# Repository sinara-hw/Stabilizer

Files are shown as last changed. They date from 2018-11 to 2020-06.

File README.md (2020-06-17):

# Stabilizer
2-channel microcontroller servo with EEM and Ethernet based on STM32 CPU

## Design Files

Design files (schematics, PCB layouts, BOMs) can be found at [Stabilizer/Releases](https://github.com/sinara-hw/Stabilizer/releases).

## Wiki

More information can be found on the [wiki](https://github.com/sinara-hw/Stabilizer/wiki).

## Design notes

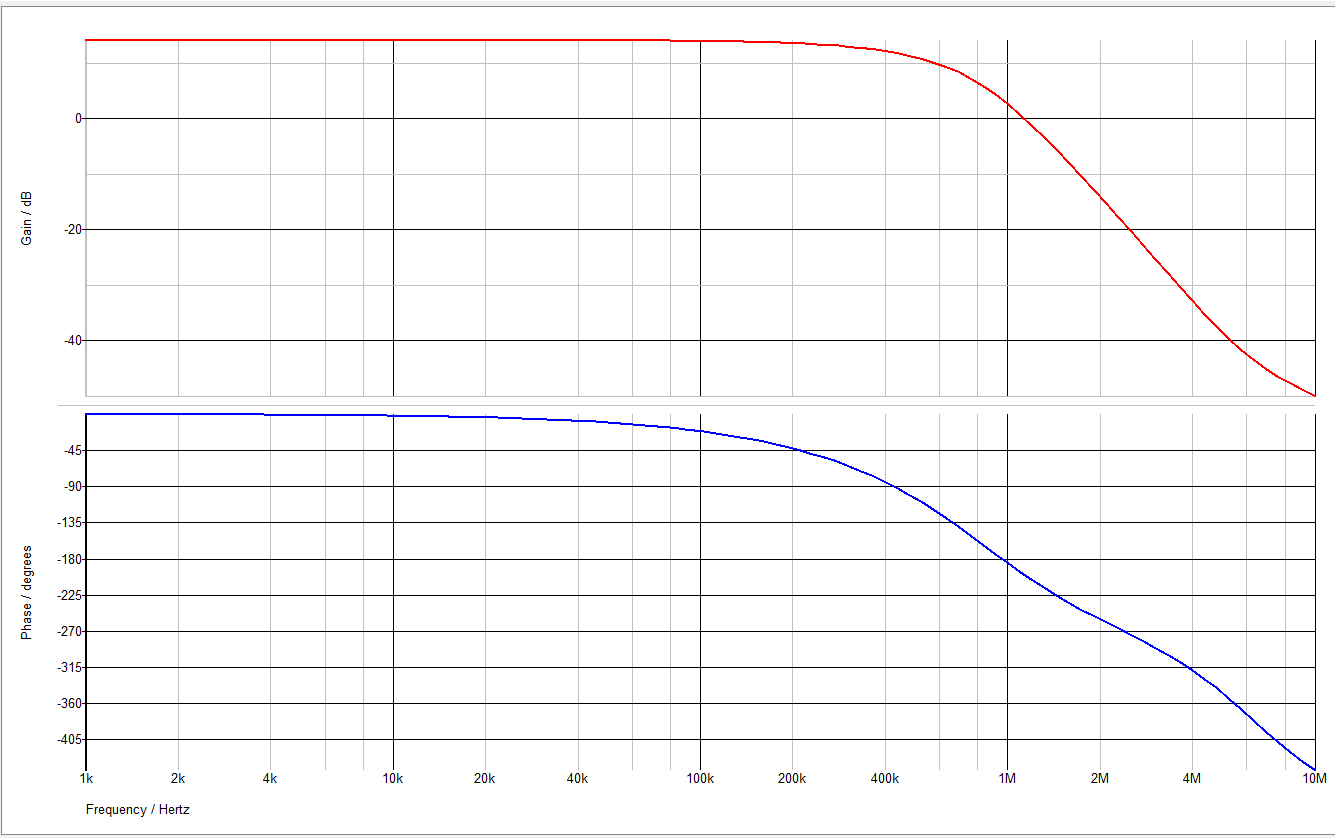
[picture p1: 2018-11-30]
SIM/DAC_filter.png

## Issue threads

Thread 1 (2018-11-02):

[RFC] New EEM: Stabilizer (Microcontroller Servo)

dtcallcock, 2018-11-02:
A fresh issue for one of the two boards proposed in [[RFC] Sinara Servo #16](https://github.com/sinara-hw/meta/issues/16).

This would be a lower performance board with the feedback loop running on a microcontroller.

- ~MSPS DACs/ADCs and ~us latency
- Ethernet for standalone operation
- Microcontroller/ethernet layout could be copied from proposed [Humpback](https://github.com/sinara-hw/meta/issues/5) target like [ST Nucleo 144](https://www.digikey.com/product-detail/en/stmicroelectronics/NUCLEO-F429ZI/497-16280-ND/5806777) to reduce risk and share development costs.
- One EEM to allow a Kasli to control lock parameters if desired _or_ to connect a DIO EEM.
- Low cost, of order $100/ch

This board could also be used as a general lab logger/controller to replace [LabJacks](https://labjack.com/products/t7).

dtcallcock, 2018-11-15:
It looks like the microcontroller ADCs will need an external reference.  Either its own 2.5V chip or divide down by 2 the external DAC's 4.096V reference?

My front panel preference would be for SMA but this is an across the board preference of mine, not specific to this board.

> PGIA is AD8250 (unless @dtcallcock objects strongly

Given it's so easy to swap out, I'm not too bothered.

> I'm less convinced about having "downstream" EEMs

Would it be simple to make it so that the single EEM can be upstream or downstream?  If it doesn't involve any real costs or compromises I think it's worth doing.

Otherwise this sounds like a good plan to me.

gkasprow, 2018-11-15:
@hartytp I did pin assignments for STM32:
- 4 individual SPI blocks for ADC and DACs
- 2x SPI slave or  master to EEM
- one UART (GPIO pins)
- Ethernet
- timer outputs (digital IOs PWM)
- 2 DACs
- 6 Diff ADC channels,
- 1 ADC trigger (GPIO pin)
- 2 I2C
- QSPI (GPIO pins)
- USB device
- JTAG
- several IOs (GPIO pins, EEM)

The question is: what special purpose pins do you want to have connected to GPIO and EEM?
Every pin can be interupt, there are ADC and DAC triggers which I already connected. Maybe some timer capture inputs? The CPU has very rich peripherals and plenty of options.
Here is CubeMX config file, if you want to look at it.
[STM32_config.zip](https://github.com/sinara-hw/Stabilizer/files/2587352/STM32_config.zip)

gkasprow, 2018-11-16:
@hartytp if we want to use termination indicator LEDs for input channels we have to switch to SMA or 8 HP panel. With BNCs I won't fit LEDs between them. I could use whole-metal BNCs which have narrower footprint, but they are not isolated and big washers would be needed.

hartytp, 2018-11-16:
>It looks like the microcontroller ADCs will need an external reference. Either its own 2.5V chip or divide down by 2 the external DAC's 4.096V reference?

Probably easiest to just add a cheap 2V5 reference rather than try to route the low noise DAC reference across the board to the microprocessor (would need a reference buffer anyway to prevent the microprocessor from adding noise to the reference). But, I'm not fussed about that. Whatever @gkasprow thinks is easiest to do.

> My front panel preference would be for SMA but this is an across the board preference of mine, not specific to this board.

For slow stuff I still like BNC. Quicker to do and undo and easy to make one's own cables to the right length for a given application. But, this is a weak preference and I'd be happy with SMA if there is a good reason for it, such as FP space.

> Given it's so easy to swap out, I'm not too bothered.

Cool. Let's go for the 8250 as default in the first revision then. I've found on Sampler that it is quite annoying how many bits of resolution one looses for signals around 2V. Having that extra factor of 5 can make a big difference.

> Would it be simple to make it so that the single EEM can be upstream or downstream? If it doesn't involve any real costs or compromises I think it's worth doing.

- @gkasprow do we need a jumper or something on the EEM connector 12V rail to prevent damage if a user connects both PoE and EEM at the same time?
- assuming the LVDS drivers are bi-directional, AFAICT the only hardware difference between upstream and downstream EEMs is the 3V3MP and the I2C. We'd need a jumper to allow the 3V3MP to be driven by stabilizer instead of Kasli, same for the I2C switch. What do you think @gkasprow?

> @hartytp if we want to use termination indicator LEDs for input channels we have to switch to SMA or 8 HP panel. With BNCs I won't fit LEDs between them.

SMAs are fine IMHO.

If anyone objects to using SMAs, I'd also be okay with removing the termination resistors. I'm not comfortable about using termination resistors without a front panel LED, since it introduces too much room for confusion.

> I could use whole-metal BNCs which have narrower footprint, but they are not isolated and big washers would be needed.

For the ADCs we do need isolation, so either isolated BNC or SMAs + washers is essential. For the DACs, isolation is not so important.

> The question is: what special purpose pins do you want to have connected to GPIO and EEM?

I'll have a think about that. @cjbe @jordens @klickverbot and others, any opinions?

hartytp, 2018-11-16:
> The question is: what special purpose pins do you want to have connected to GPIO and EEM?

For the EEMs it would be nice to have:
- An SPI bus
- One or two time outputs (if there is room)
- The rest just GPIO is fine

For the digital header:
- An SPI bus maybe QSPI?
- I2C
- A few timer outputs/PWM pins
- UART
- ADC trigger
- some gpio

AFAICT, that's basically what you sketched out above. So that seems good to me. Thanks!

hartytp, 2018-11-16:
@gkasprow thinking about this further, I'm beginning to think that we should include the trigger/integrator enable/hold TTL inputs on the front panel. i.e. we should have: 2xanalog in; 2xanalog out; 2xdigital in.

My reason for this is that integrator hold is such a common/useful feature that it would be very annoying to require an external breakout board to access it.

I think that pushes us to use an 8HP board with 3x2 stacked BNCs. I'm fine with that.

The only downside I can see from that (apart from using up more rack space, which is fine IMHO) is that it makes it harder to mount custom AFE daughter cards directly to the PCB (using the 100mil analog/digital headers as board-board connectors). @gkasprow are there any board to board connectors we can use for 8HP panels?

@cjbe thoughts?

gkasprow, 2018-11-16:
why we cannot connect potential AFE with IDC cable?
Such long 100mils headers are available, I used it several times.

hartytp, 2018-11-16:
> why we cannot connect potential AFE with IDC cable?

Well, it would need three IDC cables (main analog IO, digital IO, and probably aux analog IO). But, yes, we can do that. I think @cjbe is hoping to screw the two boards directly together without using IDCs to make things a bit simpler/reduce the amount of wiring (i.e. replace wiring with fixed board-board connectors).
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
hartytp, 2018-11-16:
> Yes, now that BNC_IDC is starting to be used for other boards, an SMA_IDC would be a nice addition.

:+1:

gkasprow, 2018-11-16:
Do you mean SMA_IDC in 4HP form factor like SMA_DIO ?

dtcallcock, 2018-11-16:
Yep.

Though I do recall @jordens thinking that having used SMA_DIO, it was too dense.  Perhaps worths a bit of pain to keep it 4HP?  Hard for me to say without having used it yet.

gkasprow, 2018-11-16:
We can distribute them more evenly across the panel to make the access easier.

gkasprow, 2018-11-17:
full support for upstream and downstream EEM requires bidir LVDS transceivers that are quite costly - 12$ per set. And we don't really know at the moment how to assign peripherals.
For 3.6$  we can have ICE40HX1K-TQ144  what has 12 LVDS transceivers and enough pins to route all not used CPU pins. The bit stream can be loaded from STM32 directly, there are a few open source [projects ](https://github.com/mystorm-org/BlackIce-II/wiki/Connections-between-the-STM32-and-the-iCE40)that uses that scenario. So no FLASH or programming header is necessary. But can add for debugging purposes and keep them DNP later.

hartytp, 2018-11-17:
Thanks @gkasprow. So...the conclusion is that a downstream EEM is doable, but definitely not "free" -- once we talk about having an FPGA on this card (which is supposed to be a simple microcontroller board) we have to ask whether this is really necessary.

My feeling is:
- We definitely should have the "upstream" EEM connector to allow Stabilizer to be controller in real time by Kasli/humpback/metlino/etc
- NB since we won't clock the MCU from the EEM connector, the real time control will be asynchronous with the sample clock, so there will be a bit of timing jitter in the real time control. That's fine IMHO.
- For the upstream EEM connector, fixed directions of all the pins is fine IMHO. I'd go for:
  - pins 0-3 4-wire SPI with one CS line, using our standard pinout;
  - pins 4, 5: upstream (carrier->stabilizer) GPIO
  - pins 6, 7: downstream (stabilizer->carrier) GPIO
- I think we shouldn't have a downstream EEM at all. If we **really** need it, let's make it a completely separate connector rather than using bi-dir LVDS drivers. Same pinout as the upstream connector, but all directions reversed.

Recapping my reasoning behind not wanting the downstream EEM functionality:
- I don't see any benefit in turning Stabiliser into a carrier for real-time control of EEMs. We already have humpback, Kasli, Metlino/Sayma for that. Why add another carrier? Making this work on a software level would require writing drivers for all the EEMs and embedding them into the stabilizer firmware. This seems like a lot of work when one could just use one of the other carriers instead
- For non real time EEMs like pounder, ethernet seems like a much better way of doing the control than using stabilizer as a carrier.
- For simple custom AFE cards like the current sense card for magnetic field stabilisation, EEM is way over the top. For those cards, it makes much more sense to just use the "digital header" on Stabiliser to provide control lines. These will be LVCMOS, which is much more convenient to deal with than LVDS for these kinds of simple applications where speed and SI aren't such an issue.

So, I don't see a clear use-case for a downstream EEM connector. Unless someone can provide a clear case where downstream EEMs are needed/really helpful, I'd prefer not to introduce them.

gkasprow, 2018-11-17:
Anyway, small FPGA would be cheaper and cosume less power  (<1mA idle) than 8 LVDS translators :)

gkasprow, 2018-11-17:
But it needs support and implementation in STM code.

gkasprow, 2018-11-17:
Let's stick with low cost FIN1027 LVDS drivers.

hartytp, 2018-11-17:
> Anyway, small FPGA would be cheaper and cosume less power (<1mA idle) than 8 LVDS translators :)
> But it needs support and implementation in STM code.
> Let's stick with low cost FIN1027 LVDS drivers.

Agreed, the FPGA has some benefits, but I don't think it's worth the software complexity in this case (although, others should feel to express themselves if they disagree). Let's stick with the FIN1027.

gkasprow, 2018-11-17:
USB won't fit on the front panel. I will place vertical one close to the CPU.

gkasprow, 2018-11-17:
@hartytp I prepared initial schematic revision.
It's here:
[Stabilizer.PDF](https://github.com/sinara-hw/Stabilizer/files/2592309/Stabilizer.PDF)

hartytp, 2018-11-17:
Wow! That was fast, thanks. I'll review it and get back to you tomorrow.

hartytp, 2018-11-18:
I believe that all feedback from here is now covered by the design review issue, so closing. Please add any further comments to the design review issue.

Thanks to all who contributed.

Closed 2018-11-18.

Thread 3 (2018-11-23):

Firmware feature requests

hartytp, 2018-11-23:
I'd like to see Stabilizer become a really nice lab tool for data acquisition, feedback, etc. The first version of the firmware will be very minimal (just a PI loop), but I want to start having a think about "killer features" that would be nice to have in the long run (pending securing funding for M-Labs/Quartiq or finding a student to implement them).

- complex configurable loop filters, implemented with low latency (the Oxford B-servo is an example of a fairly complex servo loop we use in the lab)
- record ADC traces (noise measurements, step response)
- transfer function measurement (AC signal generated by DAC, record ADC trace, probably perform FFT and other analysis in python code on a PC)
- python code to use the transfer function measurement to determine an optimal loop filter with a give bandwidth, phase margin, etc
- integrator enable/disable using TTLs/EEMs
- read/write to/from the analog + GPIO headers
- set point control via the EEM connector (n.b. this will probably be asynchronous to the sample clock)
- setting the DACs to fixed output values (override the loop filter)
- playback of waveforms from the DAC? (e.g. use this for 50Hz modulation of the coil current to cancel ambient fields, that would involve playing back a waveform in a loop, using a TTL to trigger it for synchronisation with the mains power cycle)
- modulation of loop set point from RAM for feed forward?

jordens, 2019-01-10:
By "phase locked RF source", do you mean the same function that a PLL chip gives you, i.e. Mirny?
Apart from things like integrator hold and more flexible software controls, that is.

hartytp, 2019-01-10:
Yes, just a PLL with a digitally programmable LF.

hartytp, 2019-01-10:
Anyway, even though one could do this kind of thing with Mirny in principle, it's nice to have the option of building a simple mezzanine card with some mini-curcuits bits that's tailored to a specific application such as fibre phase noise cancellation.

gkasprow, 2019-01-11:
I placed the CubeMX config file in the repo.

hartytp, 2019-06-11:
One of the features I see for stabilizer is really good diagnostics. e.g. being able to get noise spectra for the locked system. I've hacked a proof-of-principle of that onto @jordens code here https://github.com/OxfordIonTrapGroup/stabilizer/tree/adc_log

The really killer feature for me is automated system transfer function measurement. e.g. finding the open-loop system poles so that one can design an appropriate compensator. I've had a go at doing that as follows:
- simple state machine that resets whenever a user connects to port 1234
- when started, we log every ADC sample into a buffer
- when started, we add PRNG noise to the DAC output
- in reset, we clear the ADC buffer and reset our PRNG back to its seed
- python script on the PC connects and records a number of samples before disconnecting
- recreate the PRNG sequence on the PC. Transfer function is given by the ratio of the DFTs of the noise and ADC values.

Works nicely. Here is a simple test on HW. Configuration is:
- no digital LF on Stabilizer
- DAC connects to 10k series resistor, followed by 15nF shunt capacitor in parallel with the ADC input. i.e. LFP with fc at approx 1kHz

Plot looks like this after DFT (y-scale in dB)
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

- Orange is the PRNG noise (red is mean)
- blue is ADC samples
- green is inferred system TF (purple is same after decimation)
- brown is a model fit with pole at 1.3kHz

So...needs proper testing and some polishing, but seems to work quite nicely. That should make tuning up complex loops *much* faster :)

jordens, 2019-06-11:
You may want to consider choosing the PRNG period properly and take samples for exactly that period. Then the PRNG noise is strictly flat, the ADC trace doesn't need normalization, the noise is much less, and non-linearities due to uneven power disappear. This worked really well for redpid.
Nowadays with the benefit of hindsight, I would do it the way audio people do it with an exponential sweep. That has numerous advantages (works well with non-linear transfer functions, gives you extremely good inferred impulse response, even separated by response-order, has useful -- i.e. logarithmic -- power distribution accross the spectrum, much better signal to noise, works well at arbitrarily large modulation amplitudes even with nonlinear response as long as it is locked, etc. see the literature about it).

hartytp, 2019-06-11:
> You may want to consider choosing the PRNG period properly and take samples for exactly that period. Then the PRNG noise is strictly flat, the ADC trace doesn't need normalization, the noise is much less, and non-linearities due to uneven power disappear. This worked really well for redpid.

> Nowadays with the benefit of hindsight, I would do it the way audio people do it with an exponential sweep. That has numerous advantages

Yes, I did consider things like that. This was intended as a simple PoC and a fun way of dipping my toes in rust (speaking of which, I was quite pleases when I realized I can do things like this with smoltcp https://github.com/OxfordIonTrapGroup/stabilizer/blob/a66670ee7b882070c62f4a98cc35e2fc6a500f20/src/main.rs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 ). More the easiest than the best approach.

If someone can provide funding for implementing these things in a less hacky and more sophisticated way then that would be ace.

Closed 2019-06-25.

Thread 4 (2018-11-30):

v1.0 rc2 design review

hartytp, 2018-11-30:
https://github.com/sinara-hw/Stabilizer/releases/tag/v0.9rc2

hartytp, 2018-11-30:
@cjbe

hartytp, 2018-11-30:
@gkasprow I've completed my review. Looks great! Thanks.

My comments are below... Looking forward to getting these made.

- [ ] let's DNP the 50R terminators on the MMCX inputs. I always feel that 50R terminating a LVCMOS input is a bit aggressive and source termination is more effective. Good to have the pads there in case one really needs them
- [ ] am I right in thinking that the GPIO header is mechanically computable with EEM connectors, but uses different logic levels? That sounds like a recipe for disaster. Please can we make sure that it is not possible to insert an EEM connector into the GPIO header. Also, NB, since the GPIO header is not compatible with IDC<->BNC there is currently no easy way of exposing those signals via BNCs (not sure this a problem, just pointing it out cc @dtcallcock).
- [ ] can we do the connection between the microprocessor DAC outputs on page 1 by using net naming instead of nets that run over the microprocessor block
- [ ] pease can we have at least a crude power budget?
- [ ] the annotations on p2 make it look like the barrel connector is on the FP and an AXI connector is on the rear. Is that correct? I thought there is no FP power connector?
- [ ] Do we need 10uF on the DAC Vlogic supply, or is the current too low to need this?
- [ ] **Did you optimise the capacitance on the reference buffer output**? Currently it has an output capacitance of 40uF which is ten times the data sheet recommendation and could lead to reduced reference BW (higher output impedance at higher frequencies) or even instability. This should be checked in your simulation
- [ ] why are there 100nF capacitors on the DAC reference pins but not on the ADC ref pins?
- [ ] on the CPU ADC DAC schematic page, why aren't there any filter capacitors on ADC2_IN2_{P,N}?
- [ ] on the CPU ADC DAC schematic page, there are stray ADC2_IN2_{P,N} symbols
- [ ] on the reference page, please add a note giving the feedback bandwidth for IC27A
- [ ] why are the ADC reference pins driven directly from the LTC6655? They have roughly the same requirements as the DAC reference and should also be driven from the LTC3042.
- [ ] annotation "Current drain to make the reference source happier - LT3042 sources 100uA curent via SET pin" is misplaced. What does this refer to?
- [ ] on the reference page, there are some 13V symbols that don't connect to anything

gkasprow, 2018-12-01:
> let's DNP the 50R terminators on the MMCX inputs. I always feel that 50R terminating a LVCMOS input is a bit aggressive and source termination is more effective. Good to have the pads there in case one really needs them

OK, that's why I added RC termination so it works only for fast edges and do not consume energy in steady state

> am I right in thinking that the GPIO header is mechanically computable with EEM connectors, but uses different logic levels? That sounds like a recipe for disaster. Please can we make sure that it is not possible to insert an EEM connector into the GPIO header. Also, NB, since the GPIO header is not compatible with IDC<->BNC there is currently no easy way of exposing those signals via BNCs (not sure this a problem, just pointing it out cc @dtcallcock).

I did it in such way to not break the Kasli when inserted by chance. But in some circumstances it may trigger latchup, so let's not tempt the user.

> can we do the connection between the microprocessor DAC outputs on page 1 by using net naming instead of nets that run over the microprocessor block

sure

> pease can we have at least a crude power budget?

I did detailed one

> the annotations on p2 make it look like the barrel connector is on the FP and an AXI connector is on the rear. Is that correct? I thought there is no FP power connector?

true, fixed
By default DC jack  will be installed, but Molex connector can be populated for EEM operation.
If you want the opposite, let me know.

> Do we need 10uF on the DAC Vlogic supply, or is the current too low to need this?

It is roughly 1mA, but let's add one.

> Did you optimise the capacitance on the reference buffer output? Currently it has an output capacitance of 40uF which is ten times the data sheet recommendation and could lead to reduced reference BW (higher output impedance at higher frequencies) or even instability. This should be checked in your simulation

LTC and other LDOs do not like big low ESR capacitors. So we will use tantalium 10uF ones close to the DAC. Such ones are shown in DAC datasheet.

> why are there 100nF capacitors on the DAC reference pins but not on the ADC ref pins?

OK, added

> on the CPU ADC DAC schematic page, why aren't there any filter capacitors on ADC2_IN2_{P,N}?

we do not use it. I routed it to digital IO connector because they are also digital pins

> on the CPU ADC DAC schematic page, there are stray ADC2_IN2_{P,N} symbols

fixed

> on the reference page, please add a note giving the feedback bandwidth for IC27A

done

> why are the ADC reference pins driven directly from the LTC6655? They have roughly the same requirements as the DAC reference and should also be driven from the LTC3042.

true, fixed

> annotation "Current drain to make the reference source happier - LT3042 sources 100uA curent via SET pin" is misplaced. What does this refer to?

not valid anymore, removed

> on the reference page, there are some 13V symbols that don't connect to anything

fixed

> on the uC ADC page, please can you add an annotation saying "ADCs: 6xsingle-ended (0-2V) or 3 x differential (0-4V)"

done

gkasprow, 2018-12-01:
I did simulation of whole reference circuit.
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

After power on
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
Offset compensation
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
and ripples
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

hartytp, 2018-12-01:
> OK, that's why I added RC termination so it works only for fast edges and do not consume energy in steady state

Makes sense. However, 10nF is quite a large capacitance. It gives a 300kHz pole with 50R, which is a much lower frequency pole than we require to filter our fast rising edges. I'd either DNP the resistor or use a smaller capacitor.

> I did detailed one

Thanks! Particularly with PoE devices, it's really useful to have power budgets to allow one to ensure that one won't overload a switch with multiple devices drawing power.

> true, fixed
By default DC jack will be installed, but Molex connector can be populated for EEM operation.
If you want the opposite, let me know.

That sounds good.

---

> I did simulation of whole reference circuit.
> After power on

These curves look like there is quite a lot of ringing in the step response. Would it be better to decrease the OpAmp feedback bandwidth a bit to improve the stability?

> and ripples

Remind me, what is this simulation? Is this all 4 data converters (2xDAC and 2XADC) drawing 550uA at 10kHz 100kHz and 1MHz? If so, that looks great since the pk-pk ripple is only 20uV, which is much less than 1LSB (65uV).
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
cjbe, 2018-12-16:
I have had another look for board-to-board interconnects, and it seems like the Samtec ESW-1xx-33-L-D are the best option. They don't seem to be generally stocked by most distributors, but several (Digikey, Mouser, Farnell) offers them on a 3 week lead direct-ship from Samtec, which is good enough.

I definitely think it is better to use some slightly longer lead-time connectors to keep the analog / GPIO / AGPIO connectors mechanically incompatible.

cjbe, 2018-12-17:
@gkasprow it would be very useful if the ADC/DAC header (J1) was moved up or down, or further away from the front panel - even 3mm would help. In its current position space for components on the front panel is quite cut up:
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

gkasprow, 2018-12-17:
I can shift it by 5mm easily. Would it be sufficient? 10mm is  also possible with some work.

dtcallcock, 2018-12-17:
I don't see v1.0rc2 in the releases.  Am I missing something @gkasprow ?

gkasprow, 2018-12-17:
There was no v1.0rc2 yet. So far there was only v0.9rc2.

dtcallcock, 2018-12-17:
I see v0.9rc2 and v1.0rc1. Which one should be looking at?

cjbe, 2018-12-17:
@gkasprow 5mm would be perfect.

cjbe, 2018-12-18:
@gkasprow it would be useful if the P12V0A and N12V0A rails are brought out to the "ADC and DAC header" (instead of P/N13V0S).

This means that a minimal piggyback board with a couple of op-amps on would not need to have any additional regulators on.

dtcallcock, 2018-12-19:
- Can DI0/DI1 use a 5V-tolerant buffer to offer more flexibility on what random lab boxes can be plugged into them?
- Is there room for MCX instead of MMCX for DI0/DI1?  If MMCX is going to become Sinara's de-facto connector for places where SMA/BNC is too big then we should consider whether it's robust enough for use on a crate front panel.  [See also here](https://github.com/sinara-hw/Sampler/issues/13).

gkasprow, 2018-12-20:
this should fit
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

gkasprow, 2019-01-11:
switched input buffers to 5V-tolerant SN74LVC1G125DCKT
fixed TCK pulldown resistor.

hartytp, 2019-01-11:
:fireworks:

cjbe, 2019-01-11:
@gkasprow could you make the following two changes:
* it would be useful if the P12V0A and N12V0A rails are brought out to the "ADC and DAC header" (instead of P/N13V0S).
* move the MMCX digital inputs to pads with timer capture-compare inputs. E.g. move DI1 and DI2 to PA3 and PA8.

dtcallcock, 2019-01-11:
> On the 'Stabilizer AUX connector' schematic page I don't see filter capacitors on ADC1_IN1_{P,N}. Also, the capacitor on ADC2_IN2_N (C164) looks like it has the wrong value.

This still seems wrong on v1.0 Production.

Also, I don't see the bidirectional buffers required for CPCIS  & downstream EEM support.  Is that still planned?

gkasprow, 2019-01-13:
We finally decided not to implement downstream buffers due to limited use cases. But if you insist, I can add them.

gkasprow, 2019-01-13:
@cjbe DI0 and DI1 are connected to ADC trigger lines.
I can connect them in parallel to PA3 and PA8

dtcallcock, 2019-01-13:
>We finally decided not to implement downstream buffers due to limited use cases.

That's fine I just didn't see a consensus against it in the above thread so I wanted to check.

As @jordens mentioned, the killer app here is being able to do drive an Urukul and do phase/frequency servoing.  However if an RF mezzanine for Stabilizer is thought to be a better way of doing it (as @hartytp [suggests](https://github.com/sinara-hw/Stabilizer/issues/3#issuecomment-452908925)) then I'd be ok with leaving them off.  I just don't want to be in a situation where one has to resort to adding a Kasli or Humpback just for want of a few LVDS buffers.

gkasprow, 2019-01-13:
would assembly option be fine for you or you prefer a firmware-configurable direction control?

gkasprow, 2019-01-13:
OK, done
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

gkasprow, 2019-01-13:
and drivers
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

gkasprow, 2019-01-13:
they have nearly mirrored pin assignment so that was easy
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

dtcallcock, 2019-01-13:
Looks good.  Won't the receivers need some DNPed pads for 100Ohm termination though?

gkasprow, 2019-01-13:
true, just added them:)

cjbe, 2019-01-14:
@gkasprow
Could you reconnect the P/N13VS to the "CPU ADC DAC header" (J13).

This way the piggyback board has access to the noisy but higher current P/N13VS from J13, the lower current nice supply P/N12VA from J4, and P12V0 and P3V3 from J3.

cjbe, 2019-01-14:
> @cjbe DI0 and DI1 are connected to ADC trigger lines.
> I can connect them in parallel to PA3 and PA8

This is fine. If we need more IO, we could remove the connection to the ADC trigger lines, as PA3 / PA8 give us the timer inputs - we can use this to timestamp the edges and trigger the ADC at a fixed time off-set from this.

gkasprow, 2019-01-14:
I’m afraid it already was sent for production…

Closed 2019-03-19.

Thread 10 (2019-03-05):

Stabilizer errata

gkasprow, 2019-03-05:
- [x] ceramic capacitor colliding with J12 connector
- [x] add P3V3MP supply path for stand-alone operation. EEPROM may block the I2C bus
- [x] REF VCC testpoint label wrong - should be 7V instead of 12V
- [x] spelling error under CPLD (remove)

gkasprow, 2019-03-07:
- [ ] missing connection of 2V reference port with reference label. Short pin 6 RN3C with pin 3 RN4C

jmilczarek, 2019-03-13:
- [ ] micro USB port placed too far beyond PCB outline - creates tension of the front panel

gkasprow, 2019-03-13:
@jmilczarek the connector was placed on purpose to protrude via the panel, otherwise one won't be able to fully plug the USB plug. So one needs to enlarge the panel hole. Please post the image from front side. You can drag and drop the image to the github.

gkasprow, 2019-03-26:
- [ ] add RN designators on silkscreen

dtcallcock, 2019-05-31:
C164 should be 82pF, not 390pF.

gkasprow, 2019-06-03:
- [ ] 3V3MP LED (LD11) annotated as P3V3

hartytp, 2019-06-03:
> 3V3MP LED (LD11) annotated as P3V3

Is this something that's just on the EEM connector? Should it be annotated something like 3V3_EEM? One thing I found confusing when I first powered the board on is that the 3V3 light doesn't come on (usually, one LED in the strip of power on lights not coming on is a very bad sign with these designs, but here it's normal).

gkasprow, 2019-06-04:
True, MP means management power which is also confusing.

jordens, 2019-06-04:
Please label it (P)3V3(_)MP.

* We have that label on many other places on many other EEMs. Changing it is inconsistent and adds confusion.
* 3V3_MP being off hasn't been a problem in other EEMs.
* 3V3_EEM does not indicate that it can be off anymore than 3V3_MP does. It would not help.
* I don't see the problem with the label. Management power has clear meaning and I can't come up with something clearer (EEM certainly isn't clearer).
* But it would be good if you add that alternative supply path. It enables (a) standalone ops with the EEPROM and (b) enables driving another EEM (modulo pinout).

gkasprow, 2019-06-04:
OK. The last request is already on top of this issue.

airwoodix, 2019-06-05:
- [ ] fix front panel or schematic LEDs labeling (rather the latter)
On my v1.0 board + FP, I have the following:
  - FP_LED0 (green, PD5) <-> L2 on FP
  - FP_LED1 (red, PD6) <-> L3 on FP
  - FP_LED2 (green, PG4) <-> L0 on FP
  - FP_LED3 (red, PD12) <-> L1 on FP

Closed 2019-08-19.

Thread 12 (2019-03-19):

ADC SPI buffer delay

jordens, 2019-03-19:
The buffers have 4.3 ns prop delay. In roundtrip that adds up twice to the adc clk to sdo delay and the stm32 miso setup delay. This limits sample rate and transfer speed. We could play some tricks with 17 bit and cpol=1,cpha=0, dropping the first bit but it's not nice and doesn't work with all channels. Reconsider this at some suitable time.

4.3ns (SCK) + 7.4ns (ADC) + 4.3ns (MISO) + 1ns (tSUMI µC) = 17ns which would limit SCK to a 34ns period compared to the 15.6ns possible from the ADC and 20ns possible from all of the SPI channels.

gkasprow, 2019-03-19:
you can enable some delay to other lines using CPLD :D But it is not elegant.

jordens, 2019-03-20:
Adding more delay somewhere else doesn't solve the issue.

gkasprow, 2019-03-20:
What can we do here? Change the CPU to something else? Or just changing the SPI assignment solves the issue? 17bit SPI can make issues with DMA.

jordens, 2019-03-21:
We first have to decide whether those buffers are really required. If not, then remove them. If yes, then maybe there are faster ones. If not, then we can use falling edge sampling (a bit tricky, 17 bits, discard first, cpol=0, cpha=1, would work better with the 32 bit wide SPI123 buses). Or we live with it and tweak the clocking so that the ADCs run at >34ns (which would also require them to be both on SPI123 or both on SPI45 for clocking reasons and it would preclude the merging of a DAC/ADC pair on a single SPI bus).
DMA (of the SPI data) may not even be useful/required for the dominant application and I don't see an issue with it for 17 bits right now.

hartytp, 2019-03-21:
> We first have to decide whether those buffers are really required. If not, then remove them.

@jordens yes.

The motivation for these buffers wast that @gkasprow had seen issues in the past where noise on the digital lines coupled into the ADC and degraded its noise floor. I assume that this effect is strongly dependent on the particular ADC, and it's not obvious to me whether or not it will be an issue in this design.

To know that, we'd need to test. If anyone has time to do that then it would be great. Otherwise, my assumption was that -- at least in the applications I have in mind -- we can live with the delay and just slow down the ADC. But, I haven't looked into the clocking options, so that may not work.

gkasprow, 2019-03-21:
We may use faster logics, i.e. AC logic
I observed such issues with FPGAs. Maybe this particular CPU won't inject so much noise.

jordens, 2019-03-24:
Maybe the cnv buffer if the only one that we need. Or cnv and clk. @gkasprow did you see jitter/phase noise or amplitude noise? The former is not that critical for us. Iirc it was a ccd adc. That would also be mostly sensitive to amplitude noise/injection.

gkasprow, 2019-03-24:
It was an amplitude noise. The BW was too small to observe the clock jitter influence.

hartytp, 2019-06-06:
I'll try and have a look at this at some point in the next few days.

hartytp, 2019-06-10:
@jordens @gkasprow I'm happy to test this, but first I'd like to clarify what the plan is: the ADC LVCMOS inputs run from a max 2V5 supply. Am I right in thinking that the microprocessor uses fixed 3V3 logic levels? If so, how would you plan to do the level conversion?

hartytp, 2019-06-10:
The other option is to replace them with a faster buffer like http://www.ti.com/lit/ds/symlink/sn74auc2g34.pdf (@gkasprow are you aware of any faster parts that are still footprint compatible with the ones on Stabilizer?)

At that point the propagation delay doesn't affect the overall timing budget much.

unless anyone has a better idea, I'll order some of those, swap them out, re-check the noise. If that looks good I suggest we make the change for v1.1.

hartytp, 2019-06-10:
SN74AUC2G34DCKR would be the replacement PN

gkasprow, 2019-06-10:
the 74AUP1G125GW I used accepts 3.3V at its input and protects ADC against 3.3V signals from CPU
In the other direction, 2.5V is still logic H a the STM32 input so one doesn't need a level translator

hartytp, 2019-06-12:
@gkasprow okay, so how about we scrap the ADC output buffers and replace the input buffers with SN74AUC2G34? Any objections?

gkasprow, 2019-06-12:
I'm fine with that.

jordens, 2019-07-12:
Getting rid of the buffer on MISO and speeding up the buffer on CLK  by a couple ns is all that's needed.

hartytp, 2019-07-12:
I'm planning to run a quick test with the SN74AUC2G34 I have in the next couple of days. But, it probably makes sense to use a different part with better availability for the next revision (just chose that as it was footprint compatible with the current part).

gkasprow, 2019-07-12:
you can replace them with 100r resistors

hartytp, 2019-07-19:
@gkasprow the part I quoted above was a 2x buffer, so not a valid replacement. Do you know of any faster, pin-compatible replacements for 74AUP1G125GW?

> you can replace them with 100r resistors

You mean to limit the current through the ADC protection diodes?

gkasprow, 2019-07-24:
Yes, this resistor is to protect against latch-up event.

gkasprow, 2019-09-05:
we can use dual [buffer](http://www.ti.com/lit/ds/symlink/sn74auc2g34.pdf) which has 0.8...1.6ns delay at 2.5V
Alternatively we can use [241](http://www.ti.com/lit/ds/symlink/sn74auc2g241.pdf) or [126](http://www.ti.com/lit/ds/symlink/sn74auc2g126.pdf) buffer

gkasprow, 2019-09-06:
I used SN74AUC2G34DCKR

Closed 2019-09-06.

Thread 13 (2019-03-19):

SPI bus assignment

jordens, 2019-03-19:
That uC has SPI123 different from SPI45 and again different from SPI6 in terms of features, bus matrix, DMA, and clocking connections. Make it:

* AUX: SPI1: 32 bit, clocked with SPI123
* ADC0: SPI2: 32 bit, clocked with SPI123, NSS shared with TIM4_CH4 on PB9
* ADC1: SPI3: 32 bit, clocked with SPI123, NSS shared with TIM2_CH1 on PA15
* DAC0: SPI4: clocked with SPI45
* DAC1: SPI5: clocked with SPI45
* EEM: SPI6, independent D3, dedicated DMA and RAM

SPI1 and SPI6 may be swapped depending on use case

Also:

* DNP or drop the CPLD and related circuitry

gkasprow, 2019-03-19:
can they be connected in better way using CPLD?

jordens, 2019-03-20:
The cpld adds yet more delay slowing down the adc spi clock and it adds several layers of compelxity. As I said I think it's
unnecessary and suboptimal and I'd avoid it if possible. It's not a good idea to put a circuit on a board without a detailed plan when and how it is supposed to be used. Especially if this can be solved by design which is easier, cheaper, and has better performance.
I'd prefer to make seeing changes like this one as soon as possible before the next big batch is produced.

jordens, 2019-03-20:
This is not critical and it's not limiting right now. But it would be better to clean it up.

gkasprow, 2019-03-20:
The CPLD was added just in case we have issues with SPI Chip select generation in DMA mode. I had such issues in the past with F4 series CPUs. The idea is to get rid of it in the next prototype. Swapping SPI is not a problem. Actually, the firmware template should be created before completing the HW part to avoid such issues.

jordens, 2019-03-20:
Yes. so far I see no need for the cpld.
But this is not just templates. E.g. if it turns out that the spi buffers are needed and pseudo-17 bit transfers, sampling on the first edge, discarding the first bit is required to get sufficient speed, then only the first three buses would be suitable.
I would also consider merging one adc and one dac on a bus. But only after further thinking and testing this in software.

gkasprow, 2019-09-05:
@jordens can I use SPI 2,3 for DACs and SPI 4,5 for ADCs? The SPI5 MOSI conflicts with ADC IN2. So if we want to use your configuration, the AUX IO IN2 won't be differential.

jordens, 2019-09-06:
Originally, this was to tackle the SPI buffer delays (#12) with sampling trickery in the SPI peripherals that only works on SPI123. With faster buffers that's probably not be necessary anymore.

If the NSS of the ADCs are on timer output channels of the same timer type (i.e. "simple") and if the ADCs and DACs use SPIs from the same clock domains (SPI123 and SPI45 respectively), then this is OK.

gkasprow, 2019-09-06:
@jordens are you using ADC SPI in slave mode and use timer outputs to generate the NSS for both SPI and ADC?

gkasprow, 2019-09-06:
Or, you trigger ADC conversion with NSS and read in with SPI in master mode in the timer interrupt?

jordens, 2019-09-06:
Currently it's a timer that triggers a DMAMUX that drives two DMAs to the SPI configuration registers which in turn start transactions using the SPI peripheral MIDI/MSSI delays to comply with the ADC timings. On completion of the first ADC xfer an IRQ is fired that does the computation and starts the SPI transfers to the DACs. Some of it is not strictly documented (e.g. driving two DMAs from one timer or DMAing the configuration register). It might be easier and more configurable to rewire it with timer channels on NSS and separate channels to the DMA-SPI transfers (master or slave). The current way does however achieve really good latency.

dnadlinger, 2019-09-06:
For using Pounder for fibre noise cancellation, it would be useful to have a high-bandwidth link to the (presumably) [AD9959](https://www.analog.com/media/cn/technical-documentation/data-sheets/AD9959.pdf) on the AFE board. It's been a while since I've looked at the SPI clock tree/DMA structure, so I can't immediately comment on what the best bus assignment for that would be.

gkasprow, 2019-09-06:
@jordens OK, now it's clear. You want to trigger the timer with NSS signal?
If we choose SPI45 as ADC Rx master, the SPI5_NSS would be connected to TIM16_CH1,
SPI4_NSS would be shared with TIM15_CH1N. Is it acceptable?
If not, I can additionally connect these NSS lines with some other timer pins.

gkasprow, 2019-09-06:
I've read that in some STM32 one can swap MISO with MOSI. Is it possible with SPI5?

gkasprow, 2019-09-06:
There is an option called IO swap. Does it really swap MISO with MOSI so I could use SPI5 for  DAC?

gkasprow, 2019-09-06:
It seems to [work](https://community.st.com/s/question/0D50X00009XkgZFSAZ/problem-with-cubemx-generated-code-uart-intmode)

gkasprow, 2019-09-06:
So, the final SPI configuration is as follows:
    AUX: SPI1: 32 bit, clocked with SPI123
    ADC0: master SPI2: 32 bit, clocked with SPI123, NSS shared with TIM4_CH4 on PB9
    ADC1: master SPI3: 32 bit, clocked with SPI123, NSS shared with TIM2_CH1 on PA15
    DAC0: master SPI4: clocked with SPI45, swapped MOSI with MISO
    DAC1: master SPI5: clocked with SPI45, swapped MOSI with MISO
    EEM: slave SPI6, independent D3, dedicated DMA and RAM

jordens, 2019-09-06:
Yes. The io swap works.

Closed 2019-09-06.

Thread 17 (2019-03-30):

DCDC switching leakage on DAC outputs

jordens, 2019-03-30:
I think I was seeing quite some update transients/glitching/digital feedthrough on the DAC outputs outside the 500 kHz bandwidth. A couple mV IIRC. I'll post shots if I find the time and if I can reproduce it. Did the AFE filter simulation include the non-ideal behavior of the opamps at higher frequencies?

gkasprow, 2019-03-30:
I used standard TINA models. I don't know how accurately it behaves at higher frequencies.
The simulations are [here ](https://www.dropbox.com/sh/3x5q54i9ryabo9d/AABXV05j78ZGPZhp7ULNxNXpa?dl=0)

jordens, 2019-04-01:
It was in fact not at the sample rate (500 kHz) but at one of the DCDC converter frequencies (400 kHz). 16 mVpp.

hartytp, 2019-04-01:
Good catch, but ouch!

jordens, 2019-04-01:
That was from the PoE module. I am using unshielded TP cables.
When powering it from the barrel connector there is still some other switching transient at 5mVpp and 500 kHz which I can't locate.

gkasprow, 2019-04-01:
I'm not sure if I still have any Stabilized on the lab to check it.

hartytp, 2019-04-01:
@jordens do you still see any of this noise if you look at the DAC outputs on the SMA?

jordens, 2019-04-01:
Sure. That's where I generally look.

gkasprow, 2019-06-25:
I took the Stabilizer home. I supplied it from the power bank to make sure there are no ground loops.
The output is the following:
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

gkasprow, 2019-06-25:
In my case the interference period is roughly 25us.

hartytp, 2019-06-25:
Which smps is that? Is that at dc output of 0V?

gkasprow, 2019-06-25:
That's funny. I switched the power off. And the signal looks similar.
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

dnadlinger, 2019-06-25:
> That's funny. I switched the power off.

Switched the power off, as in the power to the circuit and it's actually external interference still?

gkasprow, 2019-06-25:
there are ~2.8us spikes visible after I trigger the scope with <5ns pulses and turn averaging.
But none of the converters on the board works with such frequency
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

gkasprow, 2019-06-25:
when I switch the power off, the bit interferences stay, but these small spikes go away.

gkasprow, 2019-06-25:
All power rails are quiet, only P3V3 have 20mV ripples, but not correlated wit the output

gkasprow, 2019-06-25:
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

gkasprow, 2019-06-25:
It looks like these spikes are caused by me. When I touch the board they appear, when I don't, they disappear.

gkasprow, 2019-06-25:
they are caused by the power bank. When I connect only GND with power bank, they appear.

gkasprow, 2019-06-25:
but they are induced only on the scope probe. When I touch the board GND,  at the crocodile clip, they are also there. SMA cable doesn't help much because we have CMC which has limited attenuation rate for such short pulses.

hartytp, 2019-06-25:
Wrap a ferrite on your power and scope cable?

gkasprow, 2019-06-25:
True, this could help for such a noise source.

hartytp, 2019-06-25:
Worth a go.

Anyway, pick-up from external SMPSs is always an annoying issue.

hartytp, 2019-06-25:
The bigger issue I saw -- and the one that concerns me most -- was the noise on the DAC output that scales with the programmed DAC voltage. See here https://github.com/sinara-hw/Stabilizer/issues/9#issuecomment-499091392

As this noise scales with the DAC voltage, it's definitely not due to an external source. Were you able to reproduce this?

hartytp, 2019-06-25:
> they are caused by the power bank. When I connect only GND with power bank, they appear.

I've lost track. In your measurements did you see any noise at all on the DAC output that wasn't caused by pickup from external sources?

gkasprow, 2019-06-25:
It looks that all I see comes from external sources. The noise you mentioned seems to be covered by them. I thought I'm living in a quiet spot. It is quiet, but not from EM point of view. Tomorrow I will connect it to the 12V battery directly and try to reproduce it.

hartytp, 2019-06-25:
what DAC dc output voltages did you measure?

I guess it’s possible that what I’m seeing is just filtered amplified pick up that’s getting in to the dac ref circuit. Although if that’s really the case then it’s odd that I see so much more noise on the DAC than the ADC.

hartytp, 2019-06-25:
I’ll try to find a screened box for stabilizer and take some more data.

Can you remind me of a on for a screened Eurocrats box that I can mount stabilizer in with its panel?

gkasprow, 2019-06-25:
I observed default DAC output which is 0V.

hartytp, 2019-06-25:
@glasprow ok. No the noise I see scales with the DAC output. If the output is 0V then you don’t see any noise. So you have to use a fw that programs it to full scale or something...

gkasprow, 2019-06-25:
OK, I will have a look it tomorrow.

hartytp, 2019-06-25:
:)

gkasprow, 2019-06-25:
Do you have some simple binary that outputs max value? I don't want to mess up with setting toolchain.
If you could provide me binary I could load via DFU that would make my life simpler.

hartytp, 2019-06-25:
@gkasprow sure, I'll send you something tomorrow.

What I will do is change this one line of @jordens firmware to set the DAC to a fixed value of `0xffff` https://github.com/quartiq/stabilizer/blob/d9aa3f440143f0567c1259b85b3051eef24cd349/src/main.rs#L806

@gkasprow I haven't flashed using DFU, but OpenOCD worked fine (the only slightly annoying thing was finding a recent version).

Generally, I was amazed how easy it was to build and flash the firmware. Following Robert's instructions and the [embedded rust book](https://rust-embedded.github.io/book/) it took me about half an hour to install Rust from scratch, build and flash for the first time. The Rust tooling is very impressive and makes this kind of thing very easy. I'm happy to send you a binary, but you may find it faster to make your own...

gkasprow, 2019-06-26:
I usually use IDE tools for C language under Windows (Atollic IDE) and STM32CubeMX. Never used RUST.
I have a virtual Linux machine but it always takes some time to set it up.

gkasprow, 2019-06-26:
I'm looking at the DAC reference input and it's fine.

hartytp, 2019-06-26:
@gkasprow here is a hacked version of @jordens fw. On power on, it sets DAC 0 to +fs and DAC 1 to -fs. I checked on a scope and I can clearly see the oscillations I posted before.

[release.zip](https://github.com/sinara-hw/Stabilizer/files/3329391/release.zip)

gkasprow, 2019-06-26:
@hartytp I took your files. It is elf output. I converted using

> arm-none-eabi-objcopy -O ihex

then converted to dfu and CPU doesn't start.

gkasprow, 2019-06-26:
Actually it does something. both DACs are now set to -10V. And still no issues.
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

gkasprow, 2019-06-26:
This time I supplied it from linear bench supply.

hartytp, 2019-06-26:
@gkasprow one DAC should be at +10v and one at -10V. Maybe it's not flashed correctly? Try following the instructions at https://github.com/quartiq/stabilizer for how to flash via DFU

It's possible that the noise is related to CPU activity so if the CPU isn't running then maybe the noise is gone (although, halting execution from GDB didn't make an impact on the noise I saw so I don't think that's the case).

gkasprow, 2019-06-26:
It's quite possible that it comes from the CPU.
I followed instruction, I do the verification.
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

gkasprow, 2019-06-26:
Ethernet makes huge difference
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

hartytp, 2019-06-26:
All the tests I did were with Ethernet connected btw.

gkasprow, 2019-06-26:
did you set the option bytes?
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
jordens, 2019-06-27:
Leave the option bytes at their default values.

gkasprow, 2019-06-27:
The only valid turn ratio is 1:1, otherwise, it won't work as CMC.
The CMC has two impedances, common and differential. Common is usually in uH..mH range, the differential is in nH range. If the signal is passed in a symmetrical way, nothing happens because we have the same current in both windings and the signal sees only differential inductance. But when the circuit is asymmetrical, one winding will get higher current and another will get much smaller which means that CMC is no longer serving the purpose.  The signal will see the common inductance instead. If we terminate the DAC after the CMC, at least for high frequencies, the situation would vasty improve.

jordens, 2019-06-28:
Interesting. I.e. a parallel R-C with the same R as the output R of the DAC/driver? Would be nice to see that tested.

hartytp, 2019-06-30:
> It looks like these interferences go through the output CMC.
>When I short pins 9, 10 of the AFE connector, the output gets clean.

> #9 (comment)

Interesting. @gkasprow I believe the issue you're seeing here is entirely separate to the issue I saw. Firstly, the noise spectrum is different. Beyond that, I also tried both PoE and an external supply, as well as removing the ethernet. I do not recall any of this making a significant difference (but will double check next week). Given all that and the fact that the noise scaled linearly with the DAC output voltage, I don't think that what I saw was a grounding issue.

I'll try shorting the CMC next week to be sure.

It's interesting you weren't able to reproduce my findings, but maybe not surprising since the DAC output voltages were not correct during your tests. I'll re-flash the binaries I posted next week and take a few measurements to see if I can figure this out.

hartytp, 2019-06-30:
> What does that mean for the cmcs on zotino, sampler and idc2bnc?
> ...
> It strongly depends on the particular application.

Indeed. That's the problem with these grounding issues -- it's hard to find a solution that works in all cases.

FWIW on all the tests I've done on the other boards, I've never seen the CMCs do any harm.

> Maybe we should add an option to bypass the CMCs.

Can we fit jumpers across the AFE headers? Ship the board with the jumpers in and allow users to remove them as desired?

> What would a proper "common mode ground loop suppressor" between a low impedance source (a DAC) and a high impedance sink (a trap electrode) look like?
> ...
> If we terminate the DAC after the CMC, at least for high frequencies, the situation would vastly improve.

Yes, for a trap DAC, it's probably best to use RCs to make a symmetric differential AC termination.

hartytp, 2019-06-30:
> If we terminate the DAC after the CMC, at least for high frequencies, the situation would vastly improve.
>...
> Interesting. I.e. a parallel R-C with the same R as the output R of the DAC/driver? Would be nice to see that tested.

Interesting idea.

Another approach might be to move the 30R output resistor (there to isolate the OpAmp from capacitive loads and keep it stable) to after the CMC. Put 30R on both the signal and ground with a small capacitor between the two outputs to make a high-frequency differential filter/termination.

What do you think @gkasprow? Can you try one of these approaches and see if they improve things?

Also, could you try adding the bypass capacitor (and ideally the CMC if possible0 the the PoE module and see if that helps to remove this noise?

gkasprow, 2019-09-05:
I implemented the PoE CMC and bypass caps.
For CMC it does not really matter where this 30R is because it does not influence the current which passes through the inductor.

hartytp, 2019-09-05:
I still feel like one wants inductors here rather than cmcs. What about an emi filter like the murata ones that do everything?

gkasprow, 2019-09-05:
Let's also add the inductors. the Murata filter has too low inductance - it is essentially a few ferrite beads and capacitor. CMCs are needed, otherwise, we will end up with large inductors.
In higher power SMPS designs based on FLyback converters, there is usually an inductor before the CMC, that filters the non-common mode ripples.

gkasprow, 2019-09-05:
I'm not sure if we can add any high capacitance at the input because it can break the power level negotiation process

hartytp, 2019-09-06:
Did you fix the ref buffer capacitor?

gkasprow, 2019-09-06:
yes

gkasprow, 2019-09-06:
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

hartytp, 2019-09-06:
Great!

Closed 2019-09-06.

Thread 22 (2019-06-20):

AFE headers

hartytp, 2019-06-20:
The AFE headers on the boards supplied by Technosystem do not match the 3D model and aren't the same as the ones on the BOM. Moreover, the stand-off height is a couple of mm different for one of the headers.

If we're going to use these for mounting AFE mezzanines then the stackup height must be the same for all three connectors and must match the 3D model.

@gkasprow please double check the connectors you've used and add a note somewhere that they cannot be substituted for generic shrouded headers.

gkasprow, 2019-08-19:
@hartytp can you take photo of these headers?

hartytp, 2019-08-19:
I’m away this week but will do that next week when back.

hartytp, 2019-08-28:
@gkasprow I had a go at this, but it's hard to get a photo that clearly shows the issue.

Two of the headers seem correct (measuring the dimensions, they seem to match the data sheet for the part in the BOM). However, one is significantly (>0.5mm) different and ruins the board-board stackup. Even by eye, one can see that it's different to the others.

At a guess, I'd say that someone substituted one of them for a generic part number that they already had in stock. However, to allow reliable board-board stackup these must not be substituted and should be marked as such in the BOM.

gkasprow, 2019-08-28:
On the photo, the J3 looks different than other headers.

hartytp, 2019-08-28:
Sounds about right.

gkasprow, 2019-09-06:
All AFE connectors are 3M N25xx series so it is not an issue related with the project.

hartytp, 2019-09-06:
Okay, we just need to tell ts not to make substitutions unless parts are explicitly labelled as generic

dtcallcock, 2020-01-13:
Still an issue in v1.1

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

hartytp, 2020-01-13:
For now I suggest that the mating headers on afes like pounder are shipped unsoldered and soldered in situ by users

pkozakiewicz, 2020-01-14:
We usually use generic connectors for all Sinara boards except 2x15 IDC. Unfortunately somehow I haven't seen this issue yet, so our team took what we had in our warehouse and assembled it. I see that for now Stabilizer is the only board designed for board-board stackup, so we have to pay attention to it next time. I understand that every functionality works properly.

hartytp, 2020-02-18:
@gkasprow  Is there anything we can do here to avoid this issue in future? e.g. can we add a note on the BOM that these must not be substituted?

gkasprow, 2020-02-20:
Good idea to add the note to the BOM

gkasprow, 2020-10-10:
I added note "Use original! " to the BOM

Closed 2020-10-10.

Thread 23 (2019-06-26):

PoE turns on and off with Netgear GS308P

sbourdeauducq, 2019-06-26:
When connected to a Netgear GS308P switch, the board is powered for a few seconds, then the Ethernet link establishes, then the switch cuts off power, and the cycle repeats.
After a few cycles, sometimes the board stays powered on.

sbourdeauducq, 2019-07-10:
Problem is not present on a second board.

gkasprow, 2019-07-10:
It may be a result of slightly different capacitance tolerance causing a small difference in startup current

gkasprow, 2019-08-29:
Should I buy such a switch and try to solve the issue or we can assume that the user must use 30W power delivery? I don't have any stabilizer board in my lab.

hartytp, 2019-09-06:
What should we do about this?

gkasprow, 2019-09-06:
I'm not able to recreate the issue right now. All PoE switches I have in my lab work fine.

hartytp, 2019-09-07:
Can you think of anything that might have caused this on one of @sbourdeauducq's boards? Or do you think it was a defective board?

@sbourdeauducq can you send Greg the problematic board and switch?

sbourdeauducq, 2019-09-07:
I already sent the board back, the switch is in use 24/7.

hartytp, 2019-09-07:
Sounds like an isolated incident maybe with one board. Shall we close for now and reopen if we see this again?

sbourdeauducq, 2019-09-07:
As Greg explained earlier, it could be that the board is near the maximum for low-power PoE injectors and component tolerances put it on one side or the other of the limit.

hartytp, 2019-09-07:
Which component tolerances? What do we want to do about this issue?

sbourdeauducq, 2019-09-07:
If the solution is to reduce inrush current, we should fix it.

gkasprow, 2019-09-07:
But, the issue appeared once the Ethernet LEDs went on. It means it is not inrushed current of the DC/DC converters but current consumption of the Ethernet chip or something else which triggers the overcurrent protection.
I wouldn't do any design changes until we make sure what causes this issue.
The Stabilizer has multi-stage power sequencing and the 3V3 wakes up after 5V rail
So it looks like the OVC is triggered by +/-12V LDO, because it turns on just after the 3V3 rail.
The opamps may consume some excessive current before they reach working voltage.
Can you connect the scope to +12V input rail, +3V3, +- 12VA and +5V ?
Trigger it on falling +12V and see what rail causes the issue.

hartytp, 2019-09-07:
@gkasprow do you have a stabilizer card? If so, this is easy isn't it? Replace L6 with a 0R1/0R01 resistor and look at the voltage across that resistor with a differential probe while you power stabilizer on. That will tell you the current v time profile during startup. If that's marginal according to the PoE specification then we should fix it, if not I think we can assume that there was an issue with the specific board that @sbourdeauducq had.

dtcallcock, 2019-09-07:
How important is it that POE is supported by Sinara boards given POE+ kit doesn't seem that hard to come by?  For example that GS308P (8 port | 4xPoE 53W) is a $70 switch but the GS108LP (8 port | 8xPoE+ 60W) switch is only $85.

hartytp, 2019-09-07:
It's a nice to have, as it saves on the external clutter of having PoE splitters. It's particularly useful for small modules like Thermostat where one might want to get them into a tight space with limited cabling access.

gkasprow, 2019-09-07:
The question is about scrapping POE(802.3af) and support only PoE+ (802.3at) switches

dtcallcock, 2019-09-07:
This ^

hartytp, 2019-09-07:
aah, ok.

While I don't feel too strongly, I'd prefer to keep 802.3af support unless it turns out to be particularly hard to do. The reason being that it's likely that users will get confused about the distinction and use the wrong PoE switch type anyway.

gkasprow, 2019-09-07:
The design supports, but @sbourdeauducq found a single case where it doesn't work. So, if we want to support standard PoE, one needs to debug it.

hartytp, 2019-09-07:
Replaced L6 with 1R0 to monitor current transients during power on. Powering from external 12V supply via barrel connector.

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

hartytp, 2019-09-07:
Peak is 690mA. So only 8W

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

hartytp, 2019-09-07:
Longer time scale
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

hartytp, 2019-09-07:
even longer
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

hartytp, 2019-09-07:
So, no sign of anything bad there. GS308P is specified for 15.4W per channel and our peak power is just over half that.

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

I'll try again with a PoE switch to be sure.

hartytp, 2019-09-07:
Now with a netgear prosafe jgs516pe

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

hartytp, 2019-09-07:
So, based on that, I think we can rule out inrush currents from being an issue on Stabilizer.

Unless anyone can think of anything else that could be the issue here and ,given that we cannot reproduce this issue and we no longer have access to the board it manifested on, I suggest we close this for now and repoen/debug if it occurs again. Any objections?

hartytp, 2019-09-07:
hmm...one possibility here is that the real issue is the reference buffer oscillating on your board (due to the lack of decoupling). That's really marginal and is completely unstable on some boards. That can sink a hell of a lot of current into the decoupling caps.

Anyway, we've done some work on rail stability in general, so maybe that will help...

hartytp, 2019-09-08:
Nb if you have cheap Ethernet cables with high resistamce you’ll have issues like this due to loss in the cables during the turn on current spikes

hartytp, 2019-09-10:
Okay, closing for now. Let's reopen if anyone is able to reproduce similar symptoms, or if anyone can think of any further tests we should do

sbourdeauducq, 2019-09-11:
I am using high-quality short Ethernet cables and I had already tried to replace them, without effect. They also power other devices correctly.

hartytp, 2019-09-11:
@sbourdeauducq noted. But, without access to hardware that displays this issue, I don't see any good way of debugging it further. e.g. from the sounds of it, this could have been a QC issue like a short on the PoE module rather than a design fault.

hartytp, 2019-09-11:
Note to self, the spec is

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

=

hartytp, 2019-09-11:
hmm...it's possible that the issue here is that we're right on the edge of the PoE module's minimum load specification. cf #50. Again, however, hard to tell witout hardware (if we had it, we could add a load resistor to the board and see if that fixed the problem).

hartytp, 2019-09-11:
We're nowhere near maximum current. Assume Vi = 37V, efficiency=0.8, Iout_peak=700mA. Peak input current is then 280mA, which is comfortably within spec.

hartytp, 2019-09-11:
Anyway, from a design review of the PoE design, the only potential issues I can see are the min load and the missing ESD diode. Other pairs of eyes always welcome!

sbourdeauducq, 2019-09-18:
@gkasprow I can send the switch now. Technosystem have the problematic board already.

gkasprow, 2019-09-18:
OK, let's sort this out before next  revision

gkasprow, 2019-10-21:
I got the board. I also have a switch but it works. The switch is, however, AF/AT. I ordered Netgear GS308P, the same @sbourdeauducq has. It is AF only.
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
gkasprow, 2019-10-25:
This influences all PoE circuits we have.

hartytp, 2019-10-25:
Yes. We’ll need to fix thermostat as well

hartytp, 2019-10-25:
So I think now all issues are fixed we can push out the new release quickly. That’s really great

gkasprow, 2019-10-25:
Connecting scope messes up PoE negotiation. One needs to use a battery-powered one. Essentially what it does with connected scope, it turns on the voltage which charges the capacitor and shorts the resistor and then it turns it off to turn it on again and then it fails because the resistor is shorted by MOSFET....
I think optocoupler is a better solution. I will implement both approaches so one has a choice.

gkasprow, 2019-10-25:
I will use this circuit
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

hartytp, 2019-10-25:
I’d still be inclined to hook up to cpu reset to make sure that the current limit is applied until all supplies are stable (in case the PoE is applied again before all caps have discharged)

Other than that lgtm

gkasprow, 2019-10-25:
OK, good idea.

gkasprow, 2019-10-25:
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

jordens, 2019-10-25:
https://www.electronicproducts.com/Semiconductors/Applications/Five_top_things_no_one_thinks_about_for_PoE_--_but_should.aspx

>  2) Inrush current protection is key: You might think that most PoE-enabled switches (known as power sourcing equipment or PSE) will control inrush current on the switch side, so client-side current-limiting isn’t too important. But what about your customers who use an inexpensive power injector in cases where PoE is not available from their Ethernet switch? Most low end PoE injectors (devices that sit in series between the wall jack and the client) don’t do any type of negotiation or “soft start” while applying power to a client. Make sure your PD can current limit so your capacitors don’t pop off the board during a live insertion, if your customer might use one of these injectors!

But I am surprised that the module itself is so aggressive.

jordens, 2019-10-25:
Not saying there's anything wrong with your circuit. But wouldn't inrush current limitation before the 440µF caps at the module output be a bit simpler?

gkasprow, 2019-10-25:
As I wrote a few posts above, I tried it already. I removed one 220uF cap and added a soft start but this did not help because is was not the cause of the problem. The inrush peak appears when the PoE module input caps are charged, far before it starts operation.

jordens, 2019-10-25:
Ah ok. I overlooked that. Then all good.

sbourdeauducq, 2019-10-26:
This sounds like shoddy design from the PoE module. Instead of adding workaround circuits, isn't it simpler and cleaner to use module from a different manufacturer, and test it carefully outside of the board in anticipation for similar shenanigans? The workaround circuits, if we do go this route, should probably be similarly tested as well.

gkasprow, 2019-10-26:
@sbourdeauducq this model of the switch is the only one that causes problems. I tried it with 4 other switches from other vendors and there were no issues. There is no guarantee that other PoE modules will work with your switch. The workaround is simple and it works. Other modules I found are much bigger and would require a serious redesign of the board and in case of the Thermostat, we would have to use a bigger enclosure. I also have proven PoE converter design build from discrete components but its overall cost is higher than this module cost. I've just tried and it does not work with this particular switch.
The switch you have seem to not conform to specification because it behaves in a slightly bizarre way. It detects an overcurrent and switches the load off after 3s. It looks like it does not have active overcurrent protection, but an only software one.
The module we utilize I already used in a few other applications. Nobody complained so far. It is even installed in one  HEP experiment.

gkasprow, 2019-10-26:
I already tested this workaround circuit. I did it with 2 switches which I have at home.

hartytp, 2019-10-26:
> This sounds like shoddy design from the PoE module

I don't think this is a shoddy PoE module at all. I've been generally quite impressed with it. e.g. the fact that so far I haven't been able to see any increased noised in sensitive analog circuity when powered from PoE (even without the recommended EMI filter).

As @gkasprow says, we did look at a range of modules before closing this one, and there weren't a huge number of options that fitted in with our other requirements (e.g. space). So, I still think this is the best.

If we really want to change in future then, we can always design our own footprint compatible PoE module, but that's not a game I want to get into right now.

Closed 2019-10-26.

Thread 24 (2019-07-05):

DAC noise

hartytp, 2019-07-05:
Breaking the DAC noise I reported in https://github.com/sinara-hw/Stabilizer/issues/9 out into its own issue:

With DAC 0 at +10V I see the following (AC-coupled) output driving a 1M scope:
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

- I see approx 7.5mV of noise at 140kHz
- This is with Stabilizer powered from a 12V supply, but I see the same with PoE
- No difference with ethernet + JTAG connected or disconnected
- No difference when I place a jumper across pins 9 and 10 of the analog header to short DAC_0_N to ground
- The noise I see scales with the DAC output voltage, so this seems like it must be noise on the reference. I'll post shots of different output voltages in a moment
- @gkasprow had a go at reproducing this in #9 but I do not yet trust his measurements since he wasn't getting the correct DC output. @jordens have you seen this noise in any of your tests?

hartytp, 2019-07-05:
Moved the setup to a different room. The output looks much cleaner (far fewer SMPS spikes visible) but the 140kHz noise unchanged. So I don't think it's environmental/grounding related. The good news is that, other than this noise, the output seems pretty clean...
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

hartytp, 2019-07-05:
I've turned on some digital averaging on my scope to make the noise we're looking at a little clear...

channel 0 and channel 1 both at 0xffff (+10V):
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

0xBFFF (+5V):

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

hartytp, 2019-07-05:
0x7FFF (0V):

http://10.255.6.27/GetImage
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

hartytp, 2019-07-05:
-10V (0x0000):

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

hartytp, 2019-07-05:
So, it does seem that there is some noise on the reference that's getting scaled by the DAC.

NB this was all done with the quartiq/master firmware changing a couple of lines to manually set the DAC.

hartytp, 2019-07-05:
Indeed, the noise is on the reference. here, the yellow and green traces are the two DAC outputs, with the DAC code set to 0x0000. The blue is a 10x scope probe looking at teh 100nF reference cap by DAC pin 5, the grey is a zoom in of that. Lots of averaging to pull the signal out.

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

hartytp, 2019-07-05:
@gkasprow oops.... I think this is the chopper-stabilizer amp you're using to servo out the LT3042 offsets. Look at figure 3 on the data sheet. https://www.analog.com/media/en/technical-documentation/data-sheets/ADA4528-1_4528-2.pdf

I'll depopulate some resistors to remove that reference buffer and confirm...

hartytp, 2019-07-05:
Indeed, that's the issue.

Same, but with R158 removed (inc heavy averaging)...

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

hartytp, 2019-07-05:
aah...no...removing R158 stopped the board from powering on correctly, as Rset for the LT3042 is only 39K. Replacing it with 41k allows the board to start and I see the same noise as before. So not that buffer after all...

hartytp, 2019-07-05:
I think it may be the LT3042 oscillating slightly. May not like such a capacative load.

The voltage on the set pin is clean, but the oscillations are clearly visible on the output.

hartytp, 2019-07-05:
Noise also visible on C139 (tantalum input capacitor). Maybe insufficient input capacitance. I'll try adding a large ceramic input capacitor in parallel with the 100nF.

hartytp, 2019-07-05:
Definitely an unhappy ref buffer. Definitely too much or too little capacitance somewhere...

gkasprow, 2019-07-05:
It didn't oscillate on my board.
Such LDOs tend to oscillate when too low ESR capacitor is used.
You can replace R94, R34, R105, R106 with 0.25R or even 1R and see if that helps
You can also check if IC27 is oscillating

gkasprow, 2019-07-05:
edit. Didn't read that you already removed the R158. So I'd try to increase these resistors or even remove them to see if that helps.

gkasprow, 2019-07-05:
5V is generated from SMPS, so check what is the frequency of it. But it should be far more than 140KHz. It is also passed via LDO so I'd be surprised if it was the source. Maybe IC16 is oscillating? Are the oscillations at the ref buffer input higher or lower than on the output?

hartytp, 2019-07-05:
Here is the P5V0 test point:
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

here is the LT3042 output:

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

hartytp, 2019-07-05:
So it seems that the LT3042 has almost no power supply rejection at the frequency. It's possible that the high-frequency PSRR is very low due to the heavy capacitive load.

hartytp, 2019-07-05:
> It didn't oscillate on my board.

A few mV is easy to miss when probing with a scope. So, it may have been there but hard to spot.

gkasprow, 2019-07-05:
I was observing it with 1mV/div scale and 20MHz BW.
I'd try with disconnecting the loads first.

hartytp, 2019-07-05:
hmmm... from the data sheet https://www.analog.com/media/en/technical-documentation/data-sheets/3042fb.pdf the PSRR should still be 80dB at 200kHz with 22uF output capacitance, so this doesn't seem at all right.

hartytp, 2019-07-05:
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

The PSRR drops off very rapidly with deceasing drop out voltage. However, on my board the 5V0A rail is at 4.975V, the ref output is at 4.3V. So, that's about 700mV head room, so I'd expect around 60dB.

I'll try disconnecting the loads and increasing C140 to 10uF (to ensure stability) next.

gkasprow, 2019-07-05:
I don't think it is caused by the input signal. The LDO oscillates dragging current from the input.

dnadlinger, 2019-07-05:
Ah, the minimum output capacitance is 4.7 μF – the regulator loop bandwidth is about 1 MHz, so it's possible the ESR/ESL to the ADC buffer caps is high enough to render the loop unstable with only 1 µF output capacitance.

hartytp, 2019-07-05:
@gkasprow  Yes. I believe that the output capacitance on the LT3042 is not sufficient and that's causing it to oscillate. It requires a 4.7uF ceramic output capacitor (ESR < 50mOhm and ESL < 2nH). However, we have a 1uF ceramic and then some 10uF tantalums quite far away.

Replacing the 1uF with 10uF the problem goes away.

@gkasprow the reason you didn't see this may have been that the circuit is boarderline stable so capacitor tolerances etc can cause it to move in/out of stability.

hartytp, 2019-07-05:
@dnadlinger indeed.

gkasprow, 2019-07-05:
This is this type of issue that appears once you produce more units...

hartytp, 2019-07-05:
Here is the outputs of channels 0 and 1, both set to 0xffff

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

I'll take more data in a quieter environment once i've reverted all my hardware modifications apart from the 10uF output capacitor.

hartytp, 2019-07-05:
Good news is that the output noise is now 1LSB RMS on both DACs, so it's actually a 16-bit system.

Same but different time bases

hartytp, 2019-07-05:
outputs look same at 0V as 10V. Good

gkasprow, 2019-07-05:
can you make FFT?

hartytp, 2019-07-05:
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

here you go.

gkasprow, 2019-07-05:
can you male a loop from crocodile GND clip and approach it to the SMPS converters and see if the 2 peaks on FFT are caused by them?
I'm also curious what this 8MHz peak comes from. Can you switch off the board and see if it is still there?

hartytp, 2019-07-05:
This is with heavy averaging on obviously.

There is a small SMPS peak at ~500kHz and a bump at 8MHz.

hartytp, 2019-07-05:
board off
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

board on
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

hartytp, 2019-07-05:
closer in noise, board off
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

board on
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

So there is definitely a bit of 500kHz getting through somewhere. I'll take more data in a quieter room in a bit.

gkasprow, 2019-07-05:
can you disable CMC?

hartytp, 2019-07-05:
Shorted CMC:

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

unshort:
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

So in this particular case the CMC does make things ever so slightly worse

hartytp, 2019-07-05:
The 500kHz peak is still the same.

Anyway, there are still some noise peaks there, but pretty close to the noise floor.

I'd have to check my noise model, but I guess we expect something like 15nv/rtHz output noise due to the 10k resistors, OpAmp etc.

With stabilizer unplugged, I see a scope noise floor of 160uV RMS in a 20MHz BW (brick wall filter). With stabilizer I see 360uV. Implies stabilizer RMS in 20MHz is 330uV (scope noise is negligible). Assume noise roughly white. Noise floor is 70nV/rtHz. That's high. I'd expect more like 15nV/rtHz based on the OpAmp, resistors etc.
To put it another way

hartytp, 2019-07-05:
@gkasprow the 500kSPS is the DAC update rate, so that will be a little digital feed through sneaking in just above the noise floor.

gkasprow, 2019-07-05:
makes sense.

hartytp, 2019-07-05:
Putting it on a UPV audio analyzer with floating input, I measure 100nV/rtHz white noise (instrument BW is 250kHz). Instrument noise floor is moer like 10nV/rtHz.

Gain of AFE is 5, so that's about 20nV/rtHz in-band noise. That's about right given a 12nV/rtHz for the DAC, 6nV/rtHz for each OpAmp and 12nV/rtHz for each 10k resistor.

100nV/rtHz*sqrt(500kHz) = 70uV rms. So, still a bit lower than I measured. But, might be due to grounding etc. Anyway, I don't see anything particularly worrying here, so I'm happy to call a day on this.

hartytp, 2019-07-05:
Basically, this all works as well as we can hope...good!

gkasprow, 2019-07-05:
Great! Next well-engineered module thanks to the collaborative effort.

hartytp, 2019-07-05:
Note to self, to do at some point next week:
- put LT3042 OpAmp components back
- put LT3042 input capacitors back to original values (10uF tant + 100nF ceramic)
- check noise with PoE (CMC shorted and unshorted)
- replace/remove ADC buffers

gkasprow, 2019-08-19:
@hartytp what's the conclusion then? Which components should I change at the reference buffer?

gkasprow, 2019-08-19:
I found it. I should increase LT3042 output capacitance to at least 4.7uF

Closed 2019-07-05.

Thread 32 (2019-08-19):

v1.1 changelog

gkasprow, 2019-08-19:
- moved SMA connectors 0.75mm to the front
- added PHY reset line (pin2 of CPU)
- added AT_EVENT notification. Routed to pin 8 of the CPU
- added PoE module EMI filter
- output CMCs are DNP by default and shorted by 0R resistors.
- voltage supervisor for CPU replaced with STM809
- fixed issues #10
- added P3V3_MP supply path during stand-alone operation
- moved USB connector by 1mm
- added rev ID pins
- AFE0_A0 and AFE0_A1 moved to PF2 and PF5 to make space for rev ID pins
- removed CPLD
- moved MCX by 0.5mm
- ADC SPI buffers replaced by SN74AUC2G34DCKR (#12 )
- rearranged SPI connectivity (#13 )
- increased PoE isolation barrier

hartytp, 2019-09-05:
@gkasprow when do you think you'll be able to finish this release?

jordens, 2019-09-05:
* #16: Can we change the SPI bus assignment?
* #12: SPI buffer delay
* #11: Panel design. And move the USB connector not just 0.5mm but an entire mm. The plugs are long enough and I see enough space w.r.t. RJ45 jack.

hartytp, 2019-09-05:
There are a few other things as well. e.g. the reference buffer capacitor since we don't want that oscillating.

hartytp, 2019-09-05:
@gkasprow I'm keen to buy some more stabilizer cards asap, but would like to wait to the new release, so it would be great to get this ready asap

gkasprow, 2019-09-05:
@hartytp  I'm quite busy right now because 6 of my students decided to graduate without warning, so I have a lot of paperwork to do. I'll do my best to publish the release during the weekend.

hartytp, 2019-09-05:
They grow up so fast :)

gkasprow, 2019-09-05:
True :)

hartytp, 2019-09-06:
Thanks @gkasprow ! I’ll review at some point this weekend and sign off

gkasprow, 2019-09-06:
I drafted the new release.

hartytp, 2019-09-07:
Okay, I've finished my review (everything apart from the digital bits).

Once @jordens signs off we can move to production.

Great work all. Looking over the schematic again I was please to find how high quality it is. Really nice design :)

Closed 2019-09-06.

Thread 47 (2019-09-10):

dead phy

hartytp, 2019-09-10:
@gkasprow we have the following observations:
- we had a stabilizer card that had been working fine for a while when powered from the barrel
 connector
- removed barrel connector and connected to PoE switch (netgear prosafe jgs516pe) to take some noise measurements. I've used this PoE switch before with different stabilizer cards without issue. Didn't check ethernet while it was connected to this switch
- connected back to an barrel connector
- ethernet phy seems dead (no link established)

@cjbe may have more details to add

Any idea what could have caused this? EMI associated with PoE? Should we post this card to you for investigation?

gkasprow, 2019-09-10:
Yes, post it please. I want to find what is going on before next release

hartytp, 2019-09-10:
Okay, good. I'll get it in the post to you in the am.

gkasprow, 2019-09-11:
you can short it temporarily with pin 14 which has pullup and see if that helps.

hartytp, 2019-09-11:
> @hartytp It could be an issue with dangling ethernet PHY reset pin.

It's internally pulled up isn't it?

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

gkasprow, 2019-09-11:
OK, so this should work. I also added an external pullup resistor and was looking at the wrong schematic version.

hartytp, 2019-09-11:
Well, I'll post you the board back and you can see what you think

gkasprow, 2019-09-15:
Let's wait with production until I find what's wrong with Ethernet PHY.

hartytp, 2019-09-16:
@gkasprow did you get a chance to look at the phy?

gkasprow, 2019-09-16:
Not yet. I will be in my lab tomorrow.

gkasprow, 2019-09-19:
I replaced the PHY chip and it works.
No idea how you managed to kill it.
The chip works partially, at least its digital interface.
It generates the distorted heartbeat pulses on both Rx and Tx, but they are much longer and only one long negative, then one long positive. But it should be one long negative, then one short positive-negative and one long positive. It looks like the driver was not able to drive short pulses.
The TVS is OK.
Didn't you short the Ethernet connector leads with some potential?

hartytp, 2019-09-19:
@gkasprow okay, that's what I guessed.

We plugged the ethernet into our PoE switch, but that's about it. Possible someone touched the phy, and gave it an ESD shock (although I do not think so and, anyway, it has protection diodes).

Are you sure we have all the TVS needed to protect from external ESD, phy abs max voltage ratings are respected, etc etc

hartytp, 2019-09-19:
What should we do about this issue? If we can't see a reason for this phy being dead then it's hard to be confident that it won't happen again on a new board...

gkasprow, 2019-09-19:
The TVS are not very common in Ethernet applications and they are usually not required because transformer protect the PHY against common mode ESD voltage.

hartytp, 2019-09-19:
Do you have any theories for how this part could have been damaged (other than someone accidentally shorting something etc)?

hartytp, 2019-09-19:
If not, I guess we should close for now. FWIW from a quick skim over the schematic, I didn't see anything obviously wrong or any missing protection features.

hartytp, 2019-09-19:
Also, when you're done testing, can you post the stabilizer back (TS will send us some other things soon, so maybe they can ship everything together, it's not a rush).

gkasprow, 2019-09-19:
This is PHY connection diagram that was already used in numerous designs. It could be a faulty IC. It happens from time to time. The IC was broken but in the same way on both Rx and Tx channels. If it was ESD, one driver would be damaged.
The only reason for such PHY malfunction I see right now is 3V3 transient during on phase...

hartytp, 2019-09-20:
Well, I don't see any obvious issues with the 3V3 supply in this design, so shall we close the issue? Or, do you want to e.g. do a quite step response measurement to check the regulator is stable and happy?

hartytp, 2019-09-20:
> It could be a faulty IC

NB we used this board without issue for quite a while before connecting it to PoE, so the phy definitely wasn't dead when it arrived!

gkasprow, 2019-09-20:
Yes, but IC can break due to thermal stress after some time...

hartytp, 2019-09-20:
Would that be an issue with soldering then? Or a thermal management issue?

FWIW the 3v3 rail is more like 3v45 on one board I looked at due to the feedback resistors. But, that shouldn't be an issue, right? Abs max is 3v6

gkasprow, 2019-09-20:
I checked ADDV PHY and it looks just fine
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
On my board, the PHY supply is 3.40V

hartytp, 2019-09-20:
okay, fine. Let's close this and reopen if we see any issues on other boards. For now I'll assume this was most likely some form of user error

gkasprow, 2019-09-20:
Well, it's hard to say what could be an issue. A single failure does not give enough statistics :)

hartytp, 2019-09-20:
Thanks for investigating!

Closed 2019-09-20.

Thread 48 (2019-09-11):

current probe resistor

hartytp, 2019-09-11:
@gkasprow In light of https://github.com/sinara-hw/Stabilizer/issues/23 what do you think of adding a pad for a 1206 sense resistor before the Vin+ input of the PoE module. Maybe also add test points on either side of the sense resistor to make probing easy. We would populate the resistor with 0R by default, but can mount a 2R0 or something if we need to debug any issues.

gkasprow, 2019-09-11:
Don't you want the CPU to know the power consumption? One low-cost opamp won't make a difference.

hartytp, 2019-09-11:
@gkasprow the main thing I want is an easy node I can probe to get a fast, accurate measurement of the current transients during turn on / turn off. An OpAmp is probably not ideally suited to that, although the sense amp from Booster might work (with the right pinout ;) ).

I'm less fussed about the CPU knowing the power, but I guess it could be useful. NB I'd like to be able to measure on the input of the PoE regulator not its output, so power calculation requires a measurement of both the voltage and current.

gkasprow, 2019-09-11:
OK, lest's stick with one resistor for now.
The CPU can also measure the current at the ground terminal without using Maxim chip.

gkasprow, 2019-09-15:
Added 0805 pads shorted by 0402 0R resistors to not increase the BOM.

Closed 2019-09-15.

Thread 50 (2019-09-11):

PoE minimum load

hartytp, 2019-09-11:
@gkasprow Am I missing something, or are we operating the PoE module at too low an output current (<200mA, see below) where it is not necessarily going to work due to the converter running in discontinuous mode.

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

https://github.com/sinara-hw/Stabilizer/issues/23#issuecomment-529145195

AFAICT this could be a particularly serious issue for Thermostat, where the load current could go to close to 0C if the TEC current was low.

hartytp, 2019-09-11:
Can it really be that this module can't function correctly without at least 600mW of load? If so, I'm not sure it's suitable for us (at the minimum, we'd need a switchable load resistor on thermostat to keep power enabled when the TEC current is low) :(

gkasprow, 2019-09-11:
yes, this could be also an issue with Sampler which does not consume much power when idle. I'm a bit surprised with that fact.

hartytp, 2019-09-11:
> Sampler

You mean Stabilizer, right?

Anyway, yes, the measurements I posted suggest that the current consumption on the board I was looking (see link above) at is very close to 200mA. I didn't measure closely enough to tell if it's a little above or a little below (without taking a ruler to the screen shot!). But, it's definitely marginal, so this could be the problem. Probably also depends a little on what firmware has been flashed.

What do we do? Add load resistors or look for a different PoE module which is better behaved at low loads?

hartytp, 2019-09-11:
Ironically, using crappy cables may help here as it reduces the voltage at the input to the PoE module, increasing the converter duty cycle ;)

gkasprow, 2019-09-11:
[Other PoE+](http://www.farnell.com/datasheets/1820766.pdf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) module do not have such constraint. The datasheet says something misleading about the max input inrush current that is also minimal current to maintain power signature requirment...

gkasprow, 2019-09-11:
But this module is too big to fit into enclosure.

gkasprow, 2019-09-11:
To solve this isue we can add something that consumes 200mA, for example fan :) It can be switched on by the CPU when necessary

jordens, 2019-09-11:
I remember point out the 200 mA minimum current before. But I cant find it. Back then IIRC the conclusion was that it should not be a problem. I haven't heard anything audible from those modules.

200 mA on 12V is 2.4 W, not 600 mW.

The MPS is 10mA at 20% duty, i.e. 2mA or 100mW average. We are always above that.

hartytp, 2019-09-11:
> 200 mA on 12V is 2.4 W, not 600 mW.

Indeed!

> I remember pointing out the 200 mA minimum current before. But I cant find it. Back then IIRC the conclusion was that it should not be a problem. I haven't heard anything audible from those modules.

Okay, I don't recall that discussion.

> The 803.2at MPS is 10mA at 20% duty, i.e. 2mA or 100mW average. We are always above that.

What's a good reference for these kinds of details on the af/at standards?

Anyway, agreed, if that's the standard then we should be well above that. But, how do you interpret the statement in the data sheet then? (a) it's just wrong (b) it's an acknowledgement that many PoE switches are more fussy than the standard permits (c) something I've missed? @jordens if you're really happy this isn't an issue, feel free to close.

Anyway, from a review of the schematic/datasheets and based on my understanding of the relevant standards (which is limited), this was the only potential issue I could see.

jordens, 2019-09-11:
I don't have any special references.

My reading of the datasheet is that it we need to be above ~400mW (for 100% duty MPS including inefficiencies) and if we are below 2.4W then the module may make some noise. But I haven't observed that. I would not want to add an artificial load.

hartytp, 2019-09-11:
Okay. Well, let's close this for now then. If we find another board and switch combination that show issues then it will be easy to test if a load resistor fixes the problem and re-evaluate.

Closed 2019-09-11.

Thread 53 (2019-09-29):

QSPI

gkasprow, 2019-09-29:
Consider routing QSPI to the extension connector instead of GPIO.
Another option is to add yet another high speed connector for 200Mbit QSPI link

hartytp, 2019-09-30:
> Another option is to add yet another high speed connector for 200Mbit QSPI link

If you can find something wit the right stackup, what about replacing all three connectors we currently have with a single Samtec connector (something like a lower pin-count FMC)?

hartytp, 2019-09-30:
Or, hell, go the full way and just use FMCs. i.e. make two front-pannels for Stabilizer: one which is the standard 4HP FP, and one with is 8HP with an AFE mezzanine cutout. Then put an FMC (or similar connector with fewer pins) and route all analog/digital lines on to that.

That might actually work out nicer than the current design, since getting the stackup both electrically and mechanically reliable using separate FPs and pin headers can actually be a bit of a pain...

Thoughts?

gkasprow, 2019-09-30:
going this way, we can reuse Sayma AFE form factor and connector signal assignment...

gkasprow, 2019-09-30:
The issue with BGA connectors is that you cannot make such AFE at home...

hartytp, 2019-10-21:
@jordens what was your conclusion about all of this? What (if any) changes do you want to make for pounder?

jordens, 2019-10-21:
I think there is a pounder issue for this.

dtcallcock, 2019-10-21:
https://github.com/sinara-hw/Pounder/issues/10

hartytp, 2019-10-22:
Thanks for the link. Can someone more familiar with the microprocessor pin functions confirm what if any changes that requires to stabilizer please?

This is the last issue, so I’m keen to close ASAP and get v1.1 off to manufacture

jordens, 2019-10-23:
I guess @gkasprow will propose those changes. Connect QUADSPI to the AUX header instead of the SPI1 bus that is connected now. Drop LPUART1_TX and PC8 and use those for the two additional QUADSPI data pins.
After https://github.com/sinara-hw/Stabilizer/issues/13#issuecomment-528980208 it would then make sense to wire SPI1 to the EEM header instead of SPI6.

gkasprow, 2019-10-25:
@jordens we need both SPI and QSPI.
I will connect it instead of
PD10
LPTIM1_OUT
HRTIM_CHE1
HRTIM_CHE2
HRTIM_CHA1
HRTIM_CHA2

I can also choose other pins instead

jordens, 2019-10-25:
Do we need both SPI and QSPI? I'd rather have timers available on the mezzanine.

gkasprow, 2019-10-25:
We need SPI for attenuators in Pounder and QSPI for DDS.
but, we can also connect it instead of
LPUART1_TX
PC0
PD10
PC8
UART4 Rx
and one selected timer lines.

The QSPI lines have also some useful alternative functions:
IO3
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

IO2
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

IO1
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

IO0
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

CLK
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

NSS
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

jordens, 2019-10-25:
OK. UART is less useful for the mezzanine IMO. We also have another header for a uart.
From my perspective either set of pins is fine.

gkasprow, 2019-10-26:
I mean that we already have this UART line among QSPI lines :)

gkasprow, 2019-10-26:
The header has the following pinout
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

gkasprow, 2019-10-26:
update

hartytp, 2019-10-26:
Cool. Can you post a new rc pdf please?

gkasprow, 2019-10-26:
Sure, let me finish the routing. I also added QSPI source termination.

hartytp, 2019-10-26:
Ok. But if people request final changes to the schematic don’t you want to hear them before you do the routing?

jordens, 2019-10-26:
that pinout is fine from my perspective.

Closed 2019-10-26.

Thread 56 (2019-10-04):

ERC fail

hartytp, 2019-10-04:
@gkasprow am I going crazy, or did you not run ERC? We were having some odd issues with the internal DACs, so I did some probing. The DAC reference voltage was at 3.7V (the 3V3 rail runs at 3V4 because of resistor choices, so this is clipping of an ESD diode). The 2V048 reference at C75 is fine, but the output of IC27B is railing. When I touch the input pin of that OpAmp with a probe the output voltage disappears for a moment...

Looking at the schematic, I don't see a black dot here...

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

The input is pin 5 of the OpAmp

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

but there is no connection visible on the layout

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

Did you forget to run ERC on this design ;)

@pathfinder49 I think this may explain some of the odd "firmware" issues you've been debugging

hartytp, 2019-10-04:
Not sure if this will have killed the CPU DACs.

hartytp, 2019-10-04:
@pathfinder49 we should be able to fix this easily by soldering a wire from that OpAmp to C75. Let me know if you want a hand doing that? Once it's done, check the output isn't oscillating and increase the 10R resistor if you need to to stabilize things.

gkasprow, 2019-10-05:
You are right. AD is even placing a red warning under the IC27B input.
I always do ERC, but for some reason, I skipped this one. No faintest idea of how this happened.

hartytp, 2019-10-05:
Np it’s an easy fix

gkasprow, 2019-10-25:
done. I also fived it on the board I got from @sbourdeauducq for debugging PoE

Closed 2019-10-25.

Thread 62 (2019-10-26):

Rc2 review

hartytp, 2019-10-26:
Thanks @gkasprow !

I’d like to send this to production on Monday afternoon. Please give feedback before then (or let me know if you need longer before we close this round).

hartytp, 2019-10-26:
- [ ] Why is Ic1B1C DNP?
- [ ] why is R124 undefined, not DNP?
- [ ] Was it the LT1763 that caused trouble on Urukul? Should we consider replacing it something more reliable like an LT3042? This would have the advantage of removing a BOM line.

Other than that, review complete. All looks good to me!

hartytp, 2019-10-26:
That comment about the LDO applies to +12V and +5V0A rails, but note the errata from Fastino.

Before changing, can you confirm that the LT1763 was indeed the part that caused issues on Urukul please?

Note that the review was only a look over the change log and not a full design review.

hartytp, 2019-10-26:
- [ ] Didn't you plan to replace SS16 with something rated to a higher voltage? Also, are you happy with the breakdown voltage of the FET. Since we don't have a TVS here and these components are before the EMI filter, we need to make sure that they can handle the maximum possible voltage spike (or just add a TVS to be safe!)

hartytp, 2019-10-26:
- [ ] Is the annotation about the OpAmps having JFET inputs true with the new opamps?

hartytp, 2019-10-26:
- [ ] are the dac output simulations updated for the new OpAmps?

hartytp, 2019-10-26:
- [ ] NB LT3042 needs 4.7uF min output capacitance. FWIW if we don't make this change we should, at the very least, increase IC16's output capacitance from 100nF to help ensure stability

hartytp, 2019-10-26:
Ok, now I'm done. :)

gkasprow, 2019-10-26:
The PoE rectifier uses 60V diodes. I can switch to 80V ones, but they have a [150mV higher](https://www.soemtron.org/downloads/disposals/ss14.pdf) voltage drop. However, PoE [spec](http://www.ieee802.org/3/poep_study/public/mar05/diamond_1_0305.pdf) says that max voltage is 57V, most switches use 48V though.

hartytp, 2019-10-26:
Ol if you think it’s fine then leave it as is

gkasprow, 2019-10-27:
>  Why is Ic1B1C DNP?

To lower the latency.

>
> why is R124 undefined, not DNP?

I made it DNP. It's a placeholder.

> Is the annotation about the OpAmps having JFET inputs true with the new opamps?

They have 5pA of input bias, but they are not JFET. I changed the note.

I added 60V TVS as well.

gkasprow, 2019-10-27:
I also replaced the LT1763 LDOs with LT3042

gkasprow, 2019-10-27:
new release
https://github.com/sinara-hw/Stabilizer/releases/tag/v1.1rc3

hartytp, 2019-10-27:
I can't see any issues with this design. Looks really lovely @gkasprow thanks again.

Closed 2019-10-27.

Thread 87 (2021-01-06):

P12VA LED occasionally does not illuminate

ryan-summers, 2021-01-06:
On my V1.1 stabilizer board, I have observed cases when the P12VA LED does not illuminate even after the board remains powered for a number of minutes. Probing the pin with a DMM indicates a voltage of ~0.6V.

Removing and reapplying power is sufficient to get P12VA's LED to illuminate again and probing indicates correct P12VA voltage.

Is this a known issue with v1.1 variants?

dnadlinger, 2021-01-06:
No idea about the issue, and haven't checked the schematics, but this sounds exactly like the classic regulator reverse biasing issue.

gkasprow, 2021-01-07:
the LDOs have protection diodes that should prevent such issues.
Do you have any mezzanine plugged in?
Can you check if  IC13 gets hot?

ryan-summers, 2021-01-08:
No mezzanine, IC13 remains cool the whole time. Here's a video of an occurrence (it can be repeated somewhat reliably, such as 1 boot out of 5-10?)

https://user-images.githubusercontent.com/8771450/104006880-66bd4380-51a7-11eb-80e6-5faf0f61f964.mp4

ryan-summers, 2021-01-08:
Probing Pins 1/2 (VIN) of IC13 indicates 12.96V and probing pin 3 (EN) indicates 5.737V

ryan-summers, 2021-01-08:
The LT3042 data sheet mentions:
```
A parasitic substrate diode exists between OUT and GND pins of the LT3042; do not drive OUT more than 0.3V below GND during normal operation or during a fault condition.
```

However, measuring OUT indicates -0.62 V

hartytp, 2021-01-08:
as @dnadlinger says, it sounds like the LDO needs a reverse protection diode (or if there is one then it's not doing its job)

dnadlinger, 2021-01-08:
Looks like v1.1 had a SMBJ12A on the 12V0A rail rather than a low-forward-voltage Schottky diode – try soldering in an SS16, DB2S20500L, or something like that, which should fix the issue. v1.2 has an SS16 instead.

dnadlinger, 2021-01-08:
(Also, in retrospect, I think I have seen this issue once or twice, though I blamed it on a questionable power supply at the time.)

gkasprow, 2021-04-15:
it was fixed in rev1.2 already

Closed 2021-04-15.

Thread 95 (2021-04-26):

BOM issue 3.3pF

gkasprow, 2021-04-26:
These capacitors are mounted by gluing, not soldering
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

replace them with standard parts

gkasprow, 2021-10-09:
replaced with CC0402_3.3PF_50V_0.25PF_C0G

Closed 2021-10-09.

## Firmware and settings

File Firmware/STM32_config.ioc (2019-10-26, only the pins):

Mcu.UserName=STM32H743ZITx
PA0.Signal=UART4_TX
PA1.Signal=ETH_REF_CLK
PA11.Signal=USB_OTG_FS_DM
PA12.Signal=USB_OTG_FS_DP
PA2.Signal=ETH_MDIO
PA3.Signal=LPTIM5_OUT
PA4.Signal=COMP_DAC11_group
PA5.Signal=COMP_DAC12_group
PA6.Signal=SPI1_MISO
PA7.Signal=ETH_CRS_DV
PA8.Signal=HRTIM_CHB2
PA9.Signal=USB_OTG_FS_VBUS
PB0.Signal=ADCx_INN5
PB1.Signal=ADCx_INP5
PB10.Signal=SPI2_SCK
PB11.Signal=ETH_TX_EN
PB12.Signal=ETH_TXD0
PB13.Signal=LPTIM2_OUT
PB14.Signal=SPI2_MISO
PB15.Signal=SPI2_MOSI
PB2.Signal=QUADSPI_CLK
PB5.Signal=SPI6_MOSI
PB6.Signal=LPUART1_TX
PB7.Signal=I2C1_SDA
PB8.Signal=I2C1_SCL
PB9.Signal=SPI2_NSS
PC1.Signal=ETH_MDC
PC10.Signal=SPI3_SCK
PC11.Signal=QUADSPI_BK2_NCS
PC12.Signal=SPI3_MOSI
PC2_C.Signal=ADC3_INN1
PC3_C.Signal=ADC3_INP1
PC4.Signal=ETH_RXD0
PC5.Signal=ETH_RXD1
PC6.Signal=HRTIM_CHA1
PC7.Signal=HRTIM_CHA2
PC8.Signal=HRTIM_CHB1
PC9.Signal=RCC_MCO_2
PD0.Signal=UART4_RX
PD13.Signal=LPTIM1_OUT
PD7.Signal=SPI1_MOSI
PD8.Signal=USART3_TX
PD9.Signal=USART3_RX
PE10.Signal=QUADSPI_BK2_IO3
PE2.Signal=SPI4_SCK
PE4.Signal=SPI4_NSS
PE5.Signal=SPI4_MISO
PE6.Signal=SPI4_MOSI
PE7.Signal=QUADSPI_BK2_IO0
PE8.Signal=QUADSPI_BK2_IO1
PE9.Signal=QUADSPI_BK2_IO2
PF0.Signal=I2C2_SDA
PF1.Signal=I2C2_SCL
PF10.Signal=ADC3_INN2
PF11.Signal=ADC1_INP2
PF12.Signal=ADC1_INN2
PF13.Signal=ADC2_INP2
PF14.Signal=ADC2_INN2
PF3.Signal=ADC3_INP5
PF4.Signal=ADC3_INN5
PF6.Signal=SPI5_NSS
PF7.Signal=SPI5_SCK
PF8.Signal=SPI5_MISO
PF9.Signal=ADC3_INP2
PG10.Signal=SPI1_NSS
PG11.Signal=SPI1_SCK
PG12.Signal=SPI6_MISO
PG13.Signal=SPI6_SCK
PG14.Signal=ETH_TXD1
PG6.Signal=HRTIM_CHE1
PG7.Signal=HRTIM_CHE2
PG8.Signal=SPI6_NSS
PG9.Signal=GPXTI9

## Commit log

2018-11-21 img update
    [Stabilizer.schdoc, Supply_Stabiliser.SchDoc, USB.SchDoc]
2019-01-13 added EEM downstream option
    [AUX_Analog_IO.SchDoc, CPU.SchDoc, EEM_connector.SchDoc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]
2019-09-07 added missing files
    [ADC_1CH.SchDoc, Panel_Stabilizer.PcbDoc, Stabilizer.PrjPCB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]
2019-10-27 fixed 12V regulator Rset
    [Supply_Stabiliser.SchDoc]
2019-11-24 fixed panel, replaced MCX connectors with correct 3D model.
    [Panel_Stabilizer.PcbDoc, RGMII_Ethernet.SchDoc, Stabilizer.schdoc]
2020-10-18 panel update and cosmetics
    [Panel_Stabilizer.PcbDoc, Stabilizer.schdoc]
2021-01-08 v1.2rc3 - a few cosmetic issues in schematics, TVS replaced due to EOL. No changes to Gerbers.
    [ADC_1CH.SchDoc, CPU.SchDoc, EEM_connector.SchDoc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]
2021-01-08 fixed USB divider
    [Supply_Stabiliser.SchDoc, USB.SchDoc]
2021-05-25 fixed capped vias; fixed verion number on schematics
    [CPU.SchDoc, Stabilizer.PrjPCB, Stabilizer.schdoc]
2023-03-16 v1.3.3 rc1
    [Stabilizer.PrjPCB, Stabilizer.schdoc, Supply_Stabiliser.SchDoc]
